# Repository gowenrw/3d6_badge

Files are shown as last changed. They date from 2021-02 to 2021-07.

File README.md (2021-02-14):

# 3d6 Badge

This is where all the files for the 3d6 Badge will be stored.  
This includes code and art and cad and fab files.  All the things.

## File Structure

This is the file structure of this repository

* [/](/README.md) - YOU ARE HERE
* [/art/](./art/) - Artwork and other graphics created by this project
  * /art/inspiration/ - Art and graphics pulled from other sources used as inspiration for this project
* [/code/](./code/) - All project related Code / Firmware
  * /code/altbier_pcb/ - Code folder for the production PCB(s)
  * /code/include/ - Common code includes (e.g. chipset drivers, etc.) used by the other code folders
* [/docs/](./docs/) - Documentation created by this project including web pages
* [/eda/](./eda/) - Electronic Design Automation files (i.e. KiCad)
  * /eda/altbier_pcb_3d6/ - KiCad project folder for the named project PCB(s)
* [/reference_parts/](./reference_parts/) - Documentation pulled from other sources related to components
* [./README.md](/README.md) - This File
* [./LICENSE](/LICENSE) - Currently set to MIT

Note: the reference_parts directory a link to a submodule repository.
To add it use the following cmd after downloading this template:
```
git submodule add https://github.com/gowenrw/reference_parts reference_parts
```
This will make a link to the current commit of that repo.
To update it to a newer commit after its been added use this cmd:
```
git submodule update --recursive
```

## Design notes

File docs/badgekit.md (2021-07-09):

---
layout: default
---

# 3d6 Badge Kit

The 3d6 badge kit that I am distributing contains the following items:

*  A fully assembled badge with attached battery holder
*  A Lanyard
*  3xAAA Batteries
*  A pencil with clip (for attaching to the lanyard)
*  Stickers

Badge_Kit

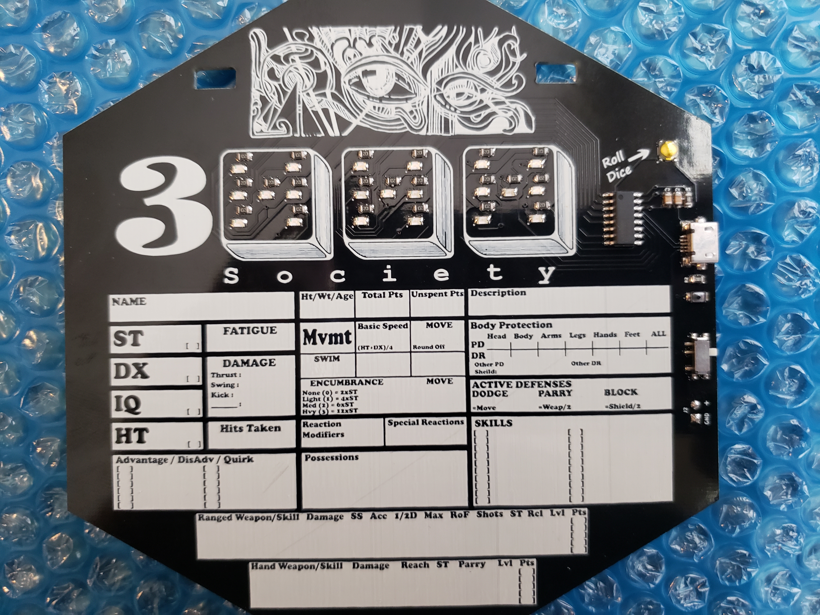
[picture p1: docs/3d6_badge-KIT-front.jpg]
Badge_Kit-Front


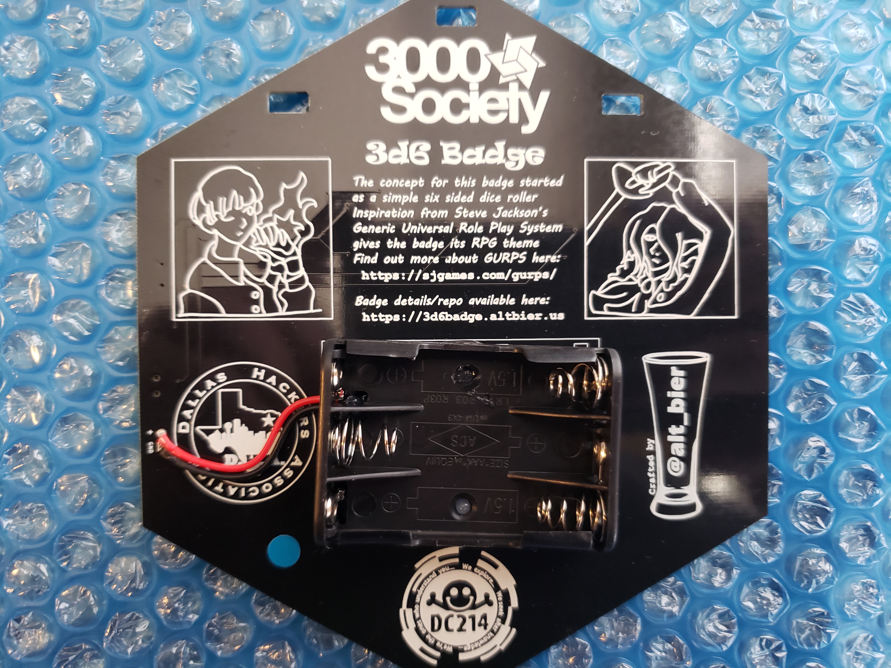
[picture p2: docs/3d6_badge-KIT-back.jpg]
Badge_Kit-Back


## Badge LED Colors

The majority of the badges I have created have Blue LEDs on them.

However, I have made limited numbers of badges with other LED colors including Red, and Pink as well as some multi-colored badges (one color per die) such as Red-White-Blue.

Badge_Colors

## Lanyard

There are several styles of lanyards since I did multiple lanyard runs.

These lanyards were randomly distributed in the kits.
So, you may get one with plastic clips or metal clips or large block lettering or small logo lettering.

They all function the same.

Badge_Kit-Lanyard

## Batteries

The batteries provided are a standard AAA non-rechargeable type.

Given the small power draw of the badge the provided batteries should last for the entire DEFCON conference (4+ days).

These can be replaced with any off the shelf AAA batteries.  

## Pencil with clip

The pencil provided is a small golf type pencil with an eraser.
It has had a clip added to it that allows for it to be attached to the lanyard.

Care should be taken to attach it securely or risk having it fall off into the void.
I would suggest attaching it into the small sewn gap holding a lanyard clip.

## Stickers

The kit contains two stickers.
The first is a new creation using the DEFCON 29 theme colors on a black background.
The second is from last years BSidesDFW Hardware Hacking Village

## Thanks

Thank You for your interest in my badge.

-- [@alt_bier](https://twitter.com/alt_bier)  - [My Contact Info](https://gowen.net/about)

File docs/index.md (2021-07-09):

---
layout: default
---

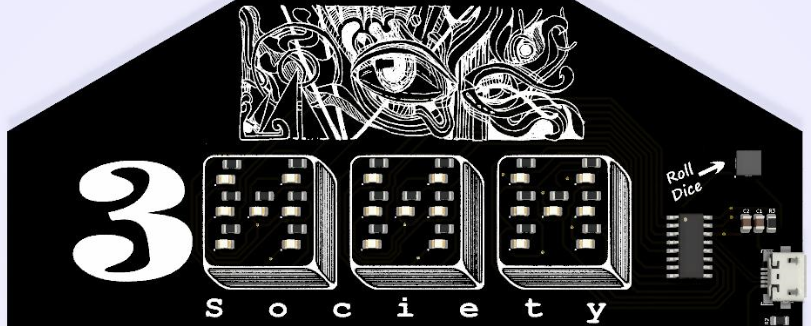
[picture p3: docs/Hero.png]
Hero Image


# 3d6 Badge

Welcome to the 3d6 Badge website.

This is where you will find information about the 3d6 badge and its repository.

-- [@alt_bier](https://twitter.com/alt_bier)  - [My Contact Info](https://gowen.net/about)

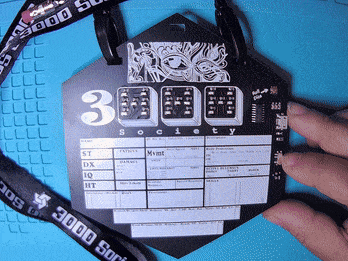
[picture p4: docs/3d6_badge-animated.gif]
Animated


---

# Concept

The concept for this badge started as a simple six sided dice roller.
It was originally just going to have two dice on it and be quite small.
But, then after discussions in the 3000 Society gaming group inspiration hit.
If we added a 3rd die the resulting 3d6 layout would be perfect for GURPS.
And thus the concept changed and the badge expanded into the GURPS player character sheet you see here.

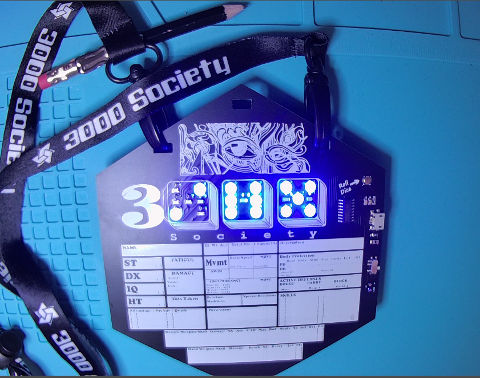
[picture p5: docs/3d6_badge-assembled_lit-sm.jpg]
Assembled-lit-small


For those not familiar with GURPS: it is the Generic Universal Role Play System developed by Steve Jackson.
You can get more information about it here: https://sjgames.com/gurps/

# Badge Kit

If you are looking for what comes in the badge kit, those details are here: [3d6 Badge Kit](badgekit.md)

# Badge Details

The details of the badge including the PCB design files and firmware and artwork are all included in this repository.

We will outline some of those details here.

## Silkscreen

The silkscreen on the front of the badge contains the GURPS player character sheet blocks (that can be written on with the included clip on pencil), the dice outlines which make up the 3000 Society logo, and a cool looking block of art at the top.

The top art block was created by my son.  I asked him to create something cool that was reminiscent of the small art blocks used as section headings in old school D&D adventure modules.
What he came up with was spectacular and captured that RPG module essence.

The silkscreen on the back of the badge contains several logos and links as well as two character portraits as one might find on an RPG character sheet.

The art for the character portraits were created by my daughter.  I asked her to create portraits of a generic magic user and melee class.  The limitations of the silkscreen media (e.g. no shading, line separation, etc.) meant she could not provide the usual detail she does with the portraits she creates for our family RPG characters.
Despite this challenge the end result is awesome and really brings the character sheet badge concept to life.

The art used for the silkscreen is available in the [art directory](https://github.com/gowenrw/3d6_badge/tree/main/art) of this repository.

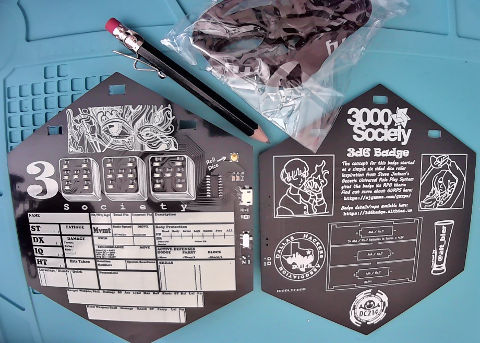
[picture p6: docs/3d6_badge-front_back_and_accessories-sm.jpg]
Front_and_Back-small


## Dice

The dice are each made up of seven LEDs arraigned to be able to lite up one through six with the look of a standard six sided die.
These LEDs are grouped into three pairs and a single so that each die requires only 4 microcontroller pins to control.

With the expansion from two to three dice the required pins went from eight to twelve, maxing out the microcontroller I chose for the badge.
With no remaining pins for a button to roll the dice I had to use the chip reset pin for this function.  So, hitting the 'Roll Dice' button is the same a powering it off and on again.

## Microcontroller

The microcontroller I chose for this badge is the CH552G IC that I have used on several other badges.  It is usually inexpensive and simple to use.

The chip shortage impacted price and availability of the CH552G.  
However, even with the higher price it was still a cheaper option than the other ICs out there.

If you want more detail about the CH552G chip I put together a video about it here:
[Intro to the CH552G Microcontroller](https://www.youtube.com/watch?v=EKhntUyfqhQ&lc=Ugyt9iKp8tLhYibYOgh4AaABAg)

The firmware for the badge and the header files for working with the CH552G are available in the [code directory](https://github.com/gowenrw/3d6_badge/tree/main/code) of this repository.

## EDA

The electronic design automation program used for this badge is KiCad.

I took great care to include and use local library files for all the schematic objects, footprints, and 3d models used in this badge.  
This way you don't have to worry about not having a file that KiCad depreciates at some point in the future.

All of the EDA files including the Gerber output files I used to have the badge manufactured are available in the [eda directory](https://github.com/gowenrw/3d6_badge/tree/main/eda) of this repository.

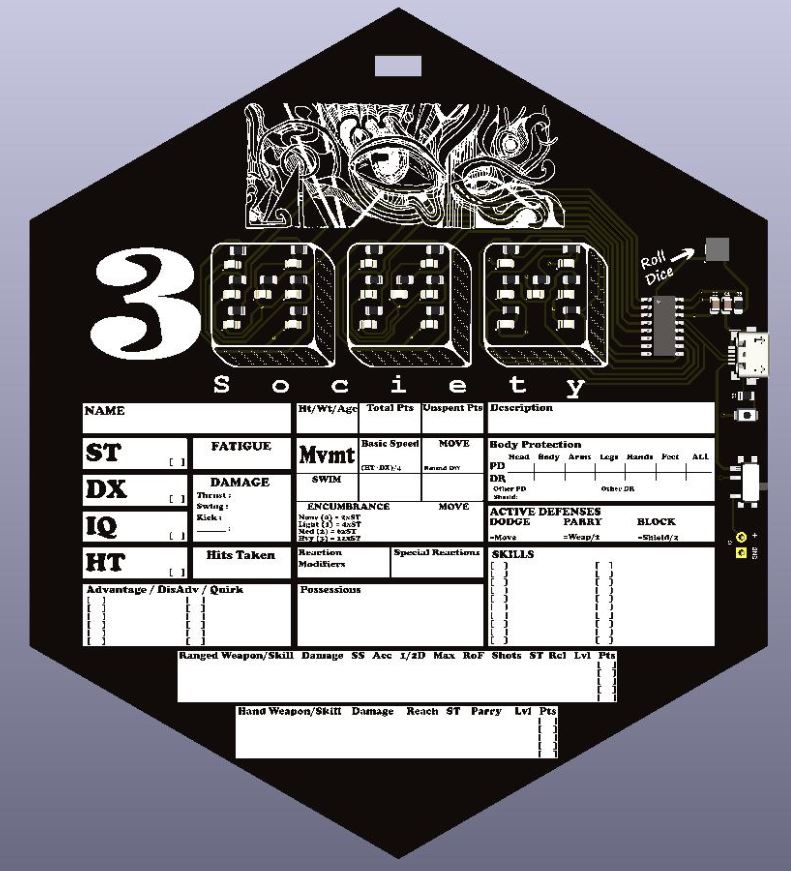
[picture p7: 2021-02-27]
eda/altbier_pcb_3d6/snapshots/altbier_pcb_3d6_3Dsnap2_crop.jpg

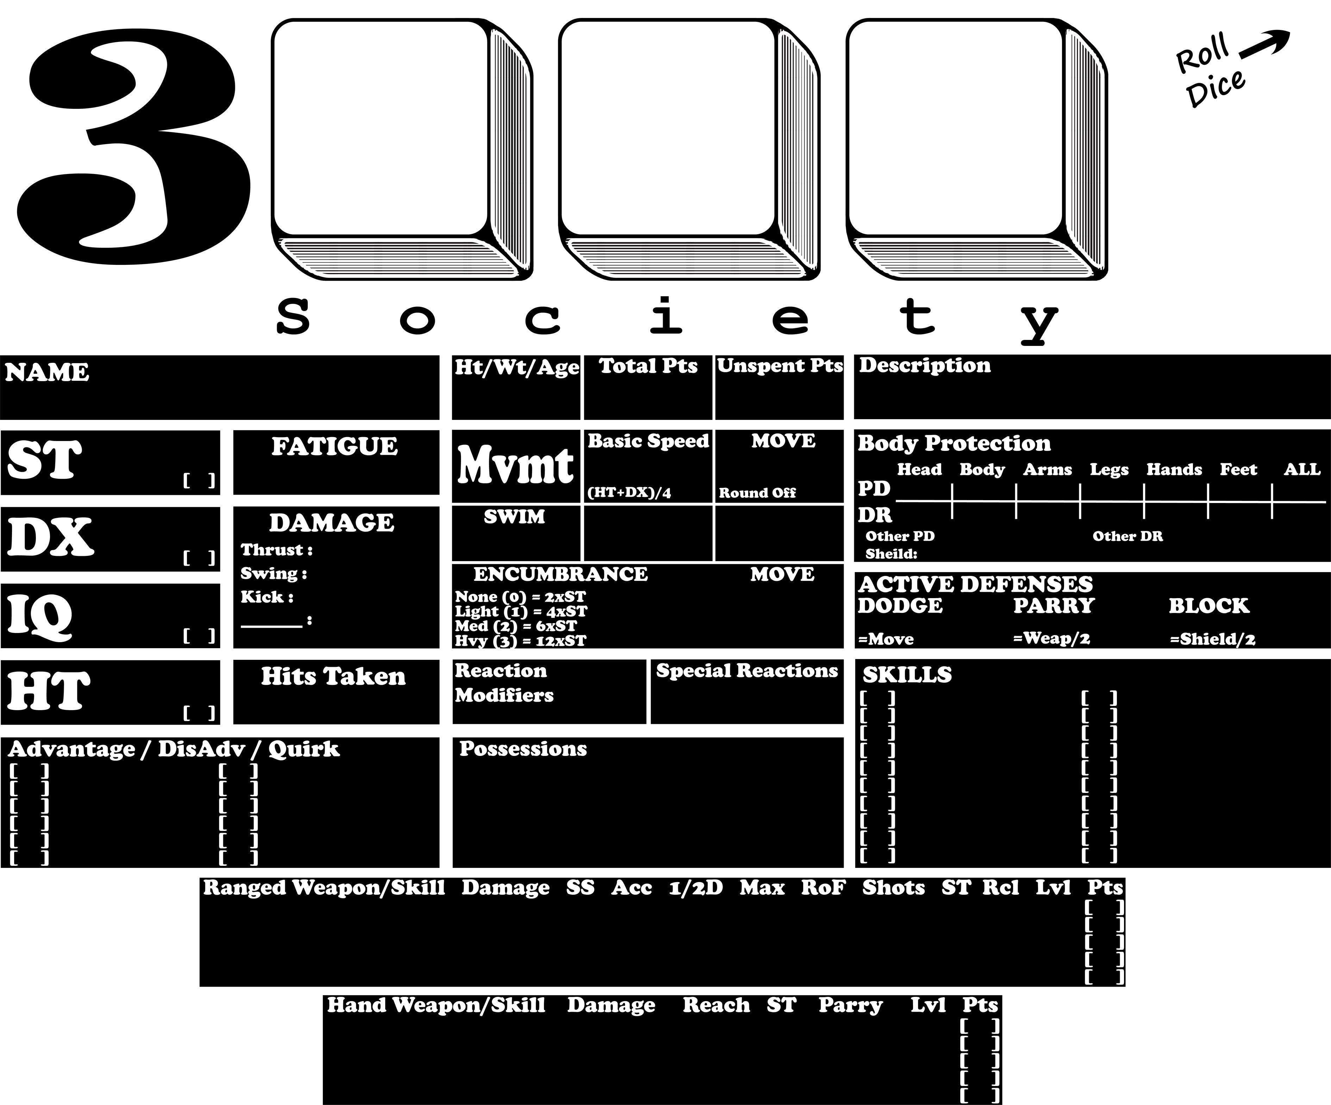
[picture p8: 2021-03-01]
art/3d6art2a.jpg

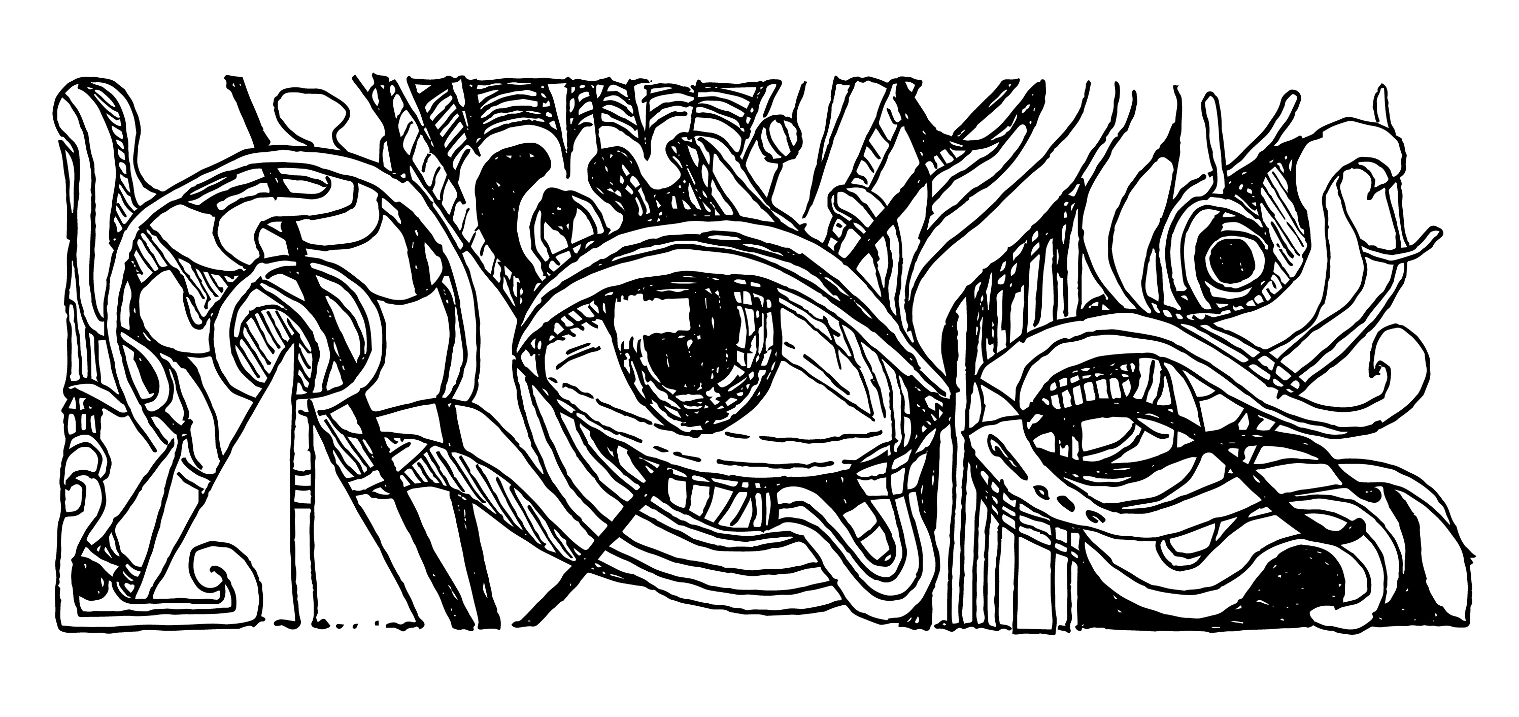
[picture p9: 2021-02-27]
art/Elliott-HandDrawn1.jpg

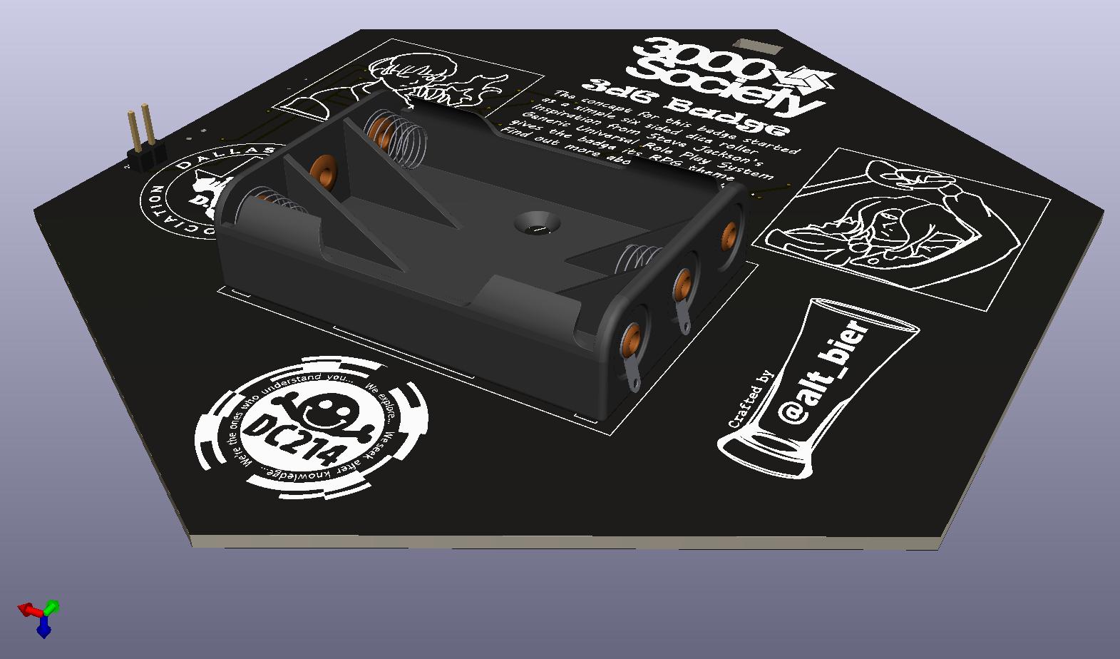
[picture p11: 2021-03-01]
eda/altbier_pcb_3d6/snapshots/altbier_pcb_3d6_3Dsnap4.jpg

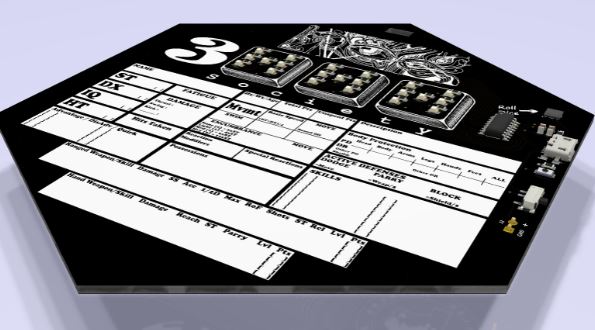
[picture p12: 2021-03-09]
eda/altbier_pcb_3d6/snapshots/altbier_pcb_3d6_3Dsnap3_small.jpg

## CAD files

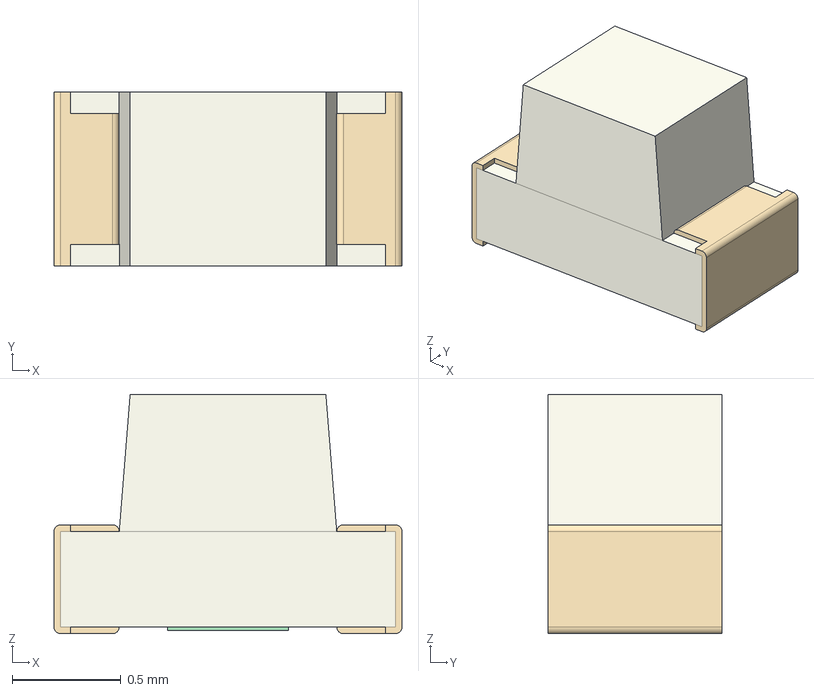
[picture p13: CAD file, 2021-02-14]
eda/altbier_pcb_3d6/3d_models/LED_0603_1608Metric.step
1.60 x 0.8 x 1.10 mm

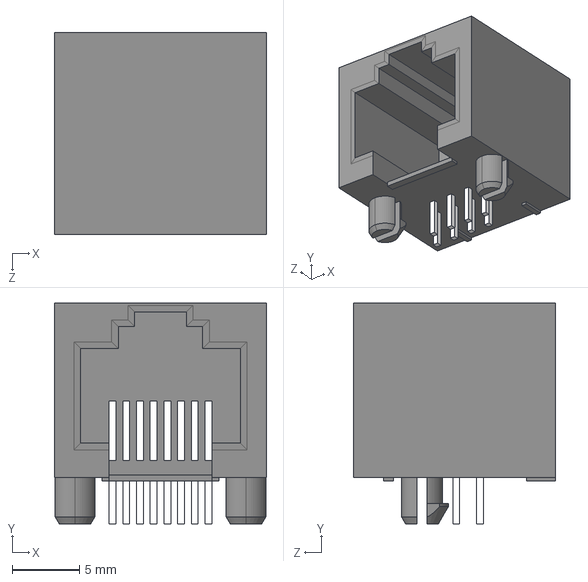
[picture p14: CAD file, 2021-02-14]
eda/altbier_pcb_3d6/3d_models/RJ45_Amphenol_RJHSE-5080-56544.STEP
15.7 x 16.4 x 15.0 mm

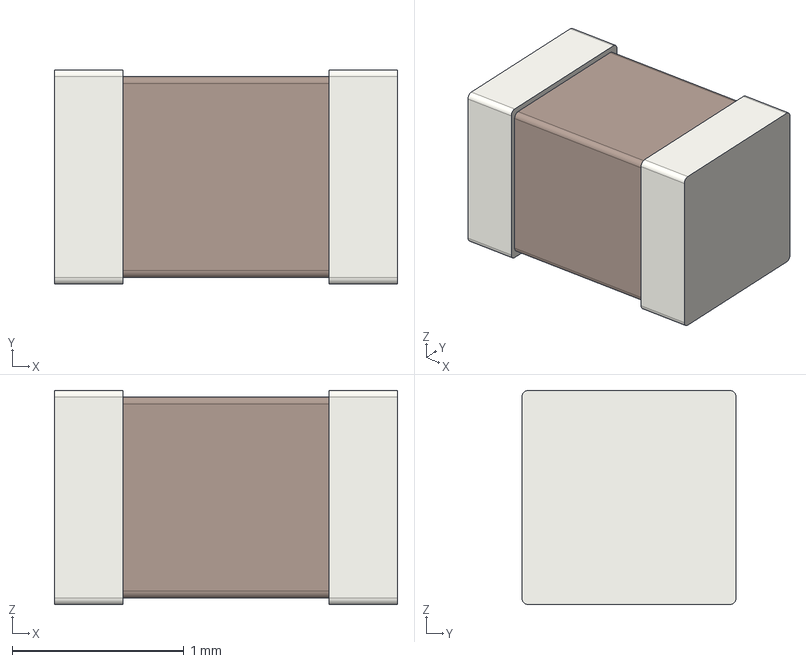
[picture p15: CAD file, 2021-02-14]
eda/altbier_pcb_3d6/3d_models/C_0805_2012Metric.step
2.00 x 1.25 x 1.25 mm

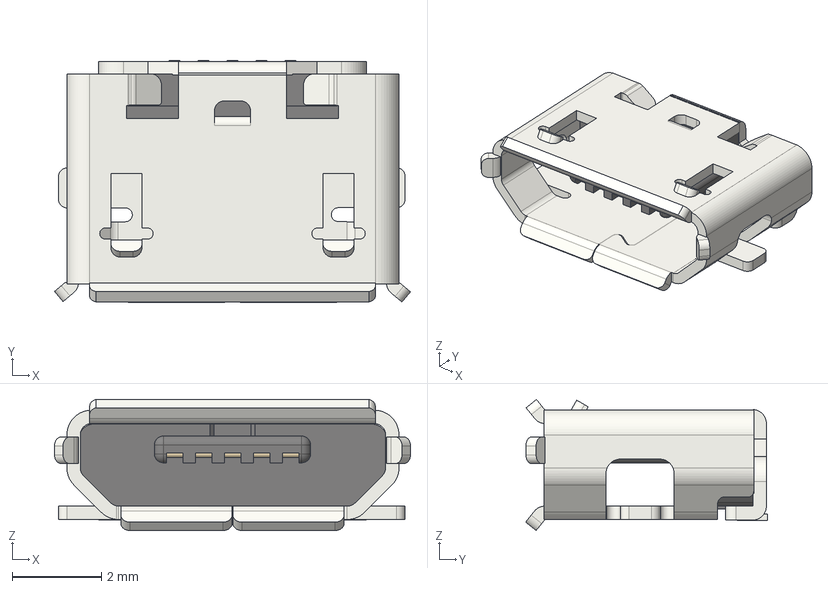
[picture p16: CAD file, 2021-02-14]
eda/altbier_pcb_3d6/3d_models/USB_Micro-B_Molex_47346-0001.step
7.98 x 5.42 x 2.94 mm

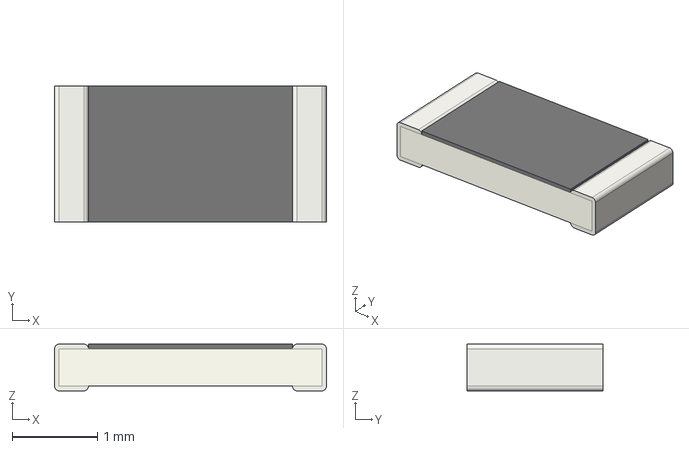
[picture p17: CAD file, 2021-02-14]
eda/altbier_pcb_3d6/3d_models/R_1206_3216Metric.step
3.20 x 1.60 x 0.55 mm

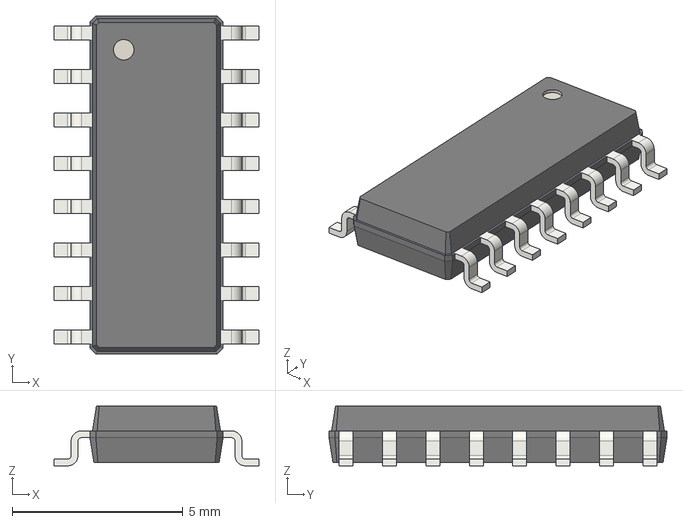
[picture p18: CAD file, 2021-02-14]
eda/altbier_pcb_3d6/3d_models/SOIC-16_3.9x9.9mm_P1.27mm.step
6.00 x 9.90 x 1.75 mm

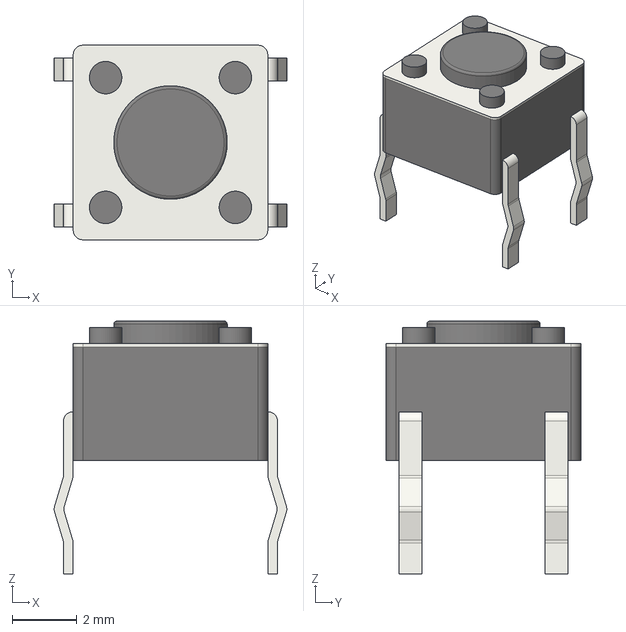
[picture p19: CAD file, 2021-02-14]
eda/altbier_pcb_3d6/3d_models/SW_PUSH_6mm.step
7.17 x 6.00 x 7.80 mm

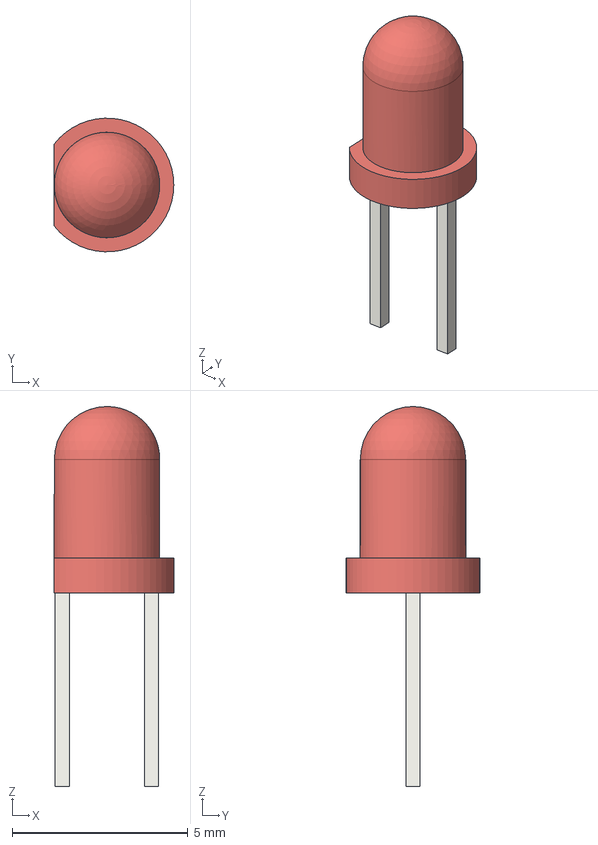
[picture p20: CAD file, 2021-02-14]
eda/altbier_pcb_3d6/3d_models/LED_D3.0mm.step
3.40 x 3.80 x 10.8 mm

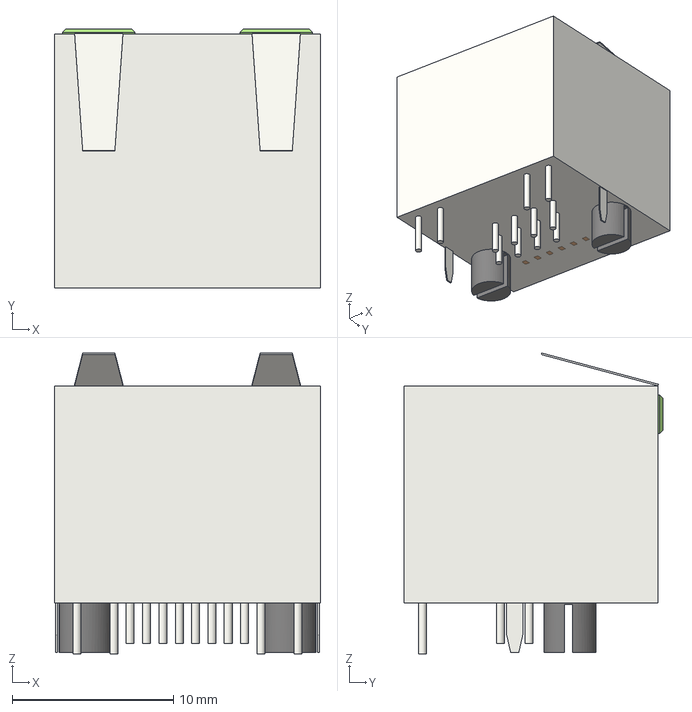
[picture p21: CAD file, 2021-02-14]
eda/altbier_pcb_3d6/3d_models/RJ45_Amphenol_RJHSE538X.step
16.5 x 16.1 x 18.7 mm

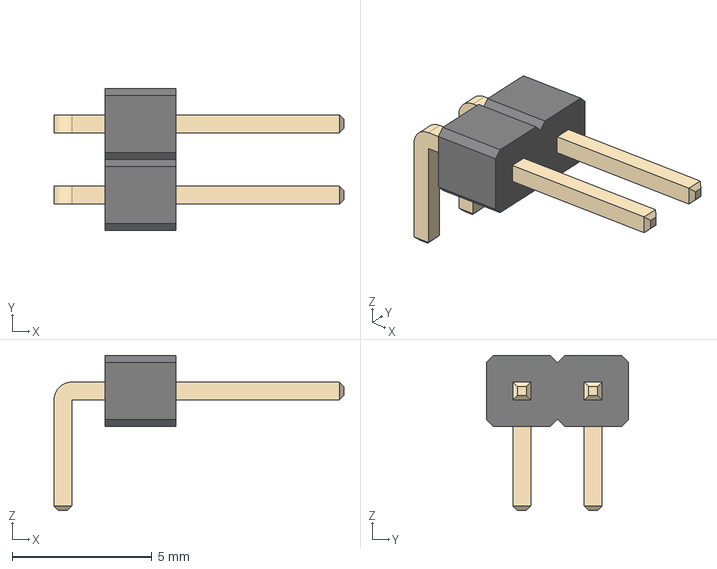
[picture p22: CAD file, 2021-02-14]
eda/altbier_pcb_3d6/3d_models/PinHeader_1x02_P2.54mm_Horizontal.step
10.4 x 5.08 x 5.54 mm

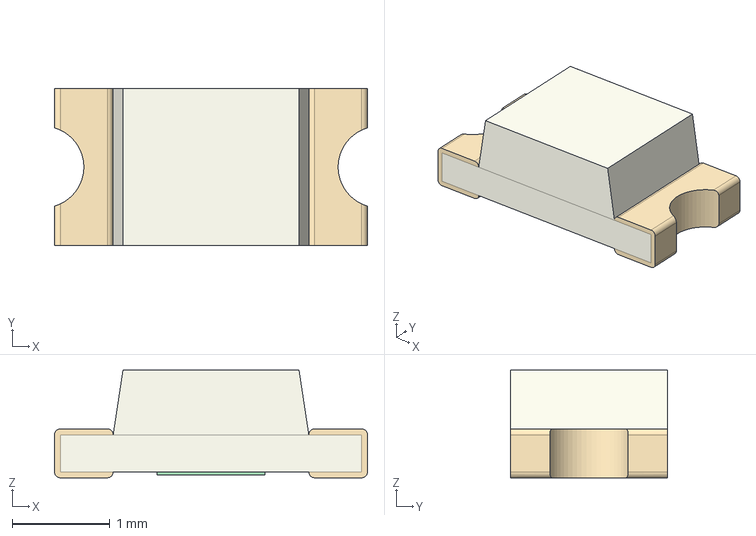
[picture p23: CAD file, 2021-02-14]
eda/altbier_pcb_3d6/3d_models/LED_1206_3216Metric_Castellated.step
3.20 x 1.60 x 1.10 mm

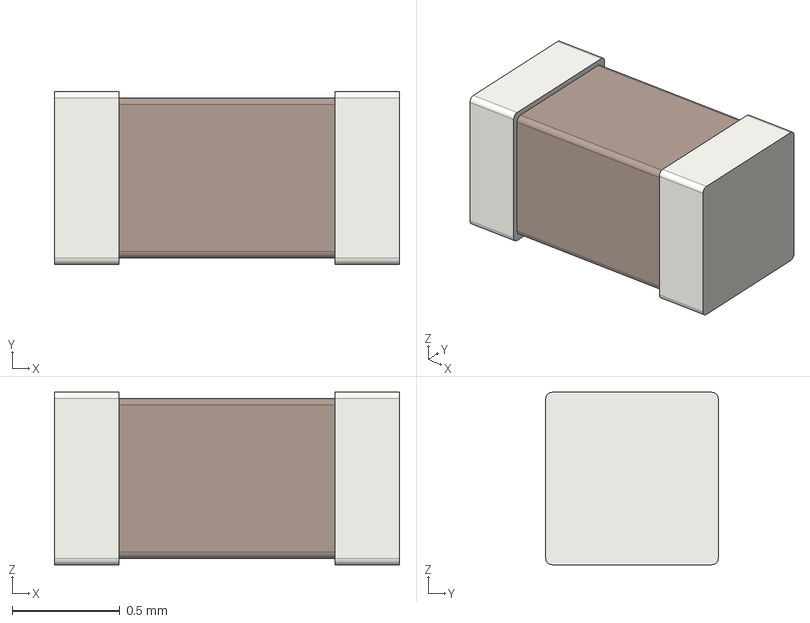
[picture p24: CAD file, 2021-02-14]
eda/altbier_pcb_3d6/3d_models/C_0603_1608Metric.step
1.60 x 0.8 x 0.8 mm

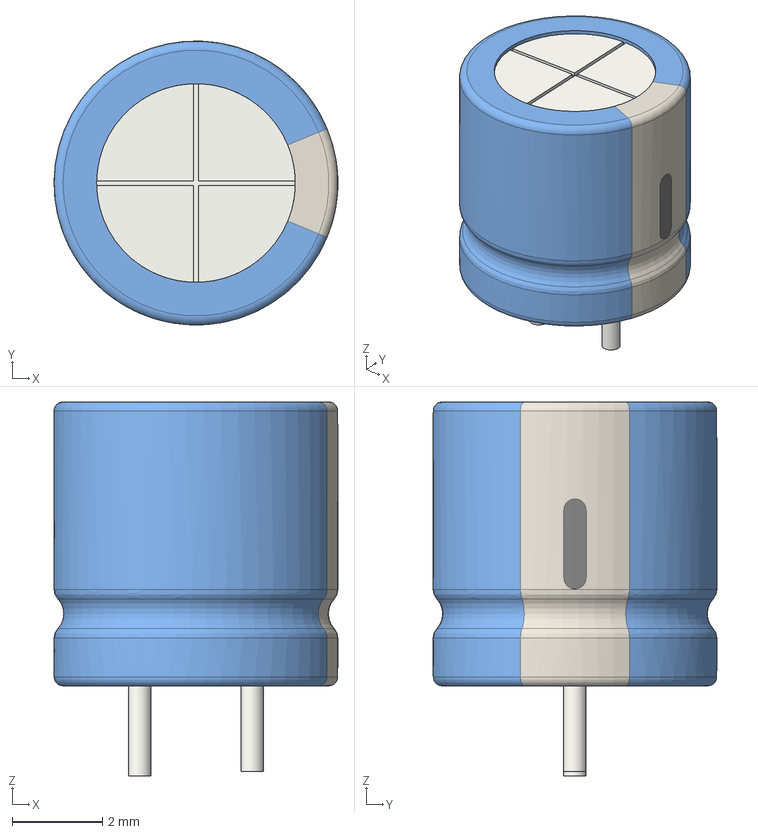
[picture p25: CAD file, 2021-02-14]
eda/altbier_pcb_3d6/3d_models/CP_Radial_D6.3mm_P2.50mm.step
6.30 x 6.30 x 8.30 mm

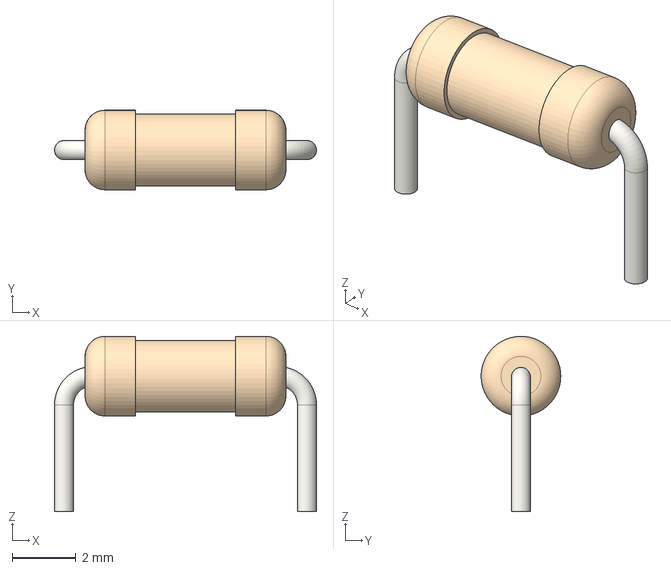
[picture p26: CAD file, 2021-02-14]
eda/altbier_pcb_3d6/3d_models/R_Axial_DIN0207_L6.3mm_D2.5mm_P7.62mm_Horizontal.step
8.22 x 2.50 x 5.50 mm

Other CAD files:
eda/altbier_pcb_3d6/3d_models/LED_0603_1608Metric_Castellated.step
eda/altbier_pcb_3d6/3d_models/LED_D5.0mm-4_RGB.step
eda/altbier_pcb_3d6/3d_models/R_0805_2012Metric.step
eda/altbier_pcb_3d6/3d_models/Battery_Holder_3xAAA_Simple.step
eda/altbier_pcb_3d6/3d_models/C_1206_3216Metric.step
eda/altbier_pcb_3d6/3d_models/C_Disc_D3.0mm_W2.0mm_P2.50mm.step
eda/altbier_pcb_3d6/3d_models/C_Rect_L4.6mm_W2.0mm_P2.50mm_MKS02_FKP02.step
eda/altbier_pcb_3d6/3d_models/LED_0805_2012Metric.step
eda/altbier_pcb_3d6/3d_models/LED_0805_2012Metric_Castellated.step
eda/altbier_pcb_3d6/3d_models/LED_1206_3216Metric.step
eda/altbier_pcb_3d6/3d_models/LED_D5.0mm-4_RGB_Neo.step
eda/altbier_pcb_3d6/3d_models/LED_D5.0mm.step
eda/altbier_pcb_3d6/3d_models/LED_D8.0mm.step
eda/altbier_pcb_3d6/3d_models/PinHeader_1x02_P2.54mm_Vertical.step
eda/altbier_pcb_3d6/3d_models/PinHeader_1x08_P2.54mm_Horizontal.step
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

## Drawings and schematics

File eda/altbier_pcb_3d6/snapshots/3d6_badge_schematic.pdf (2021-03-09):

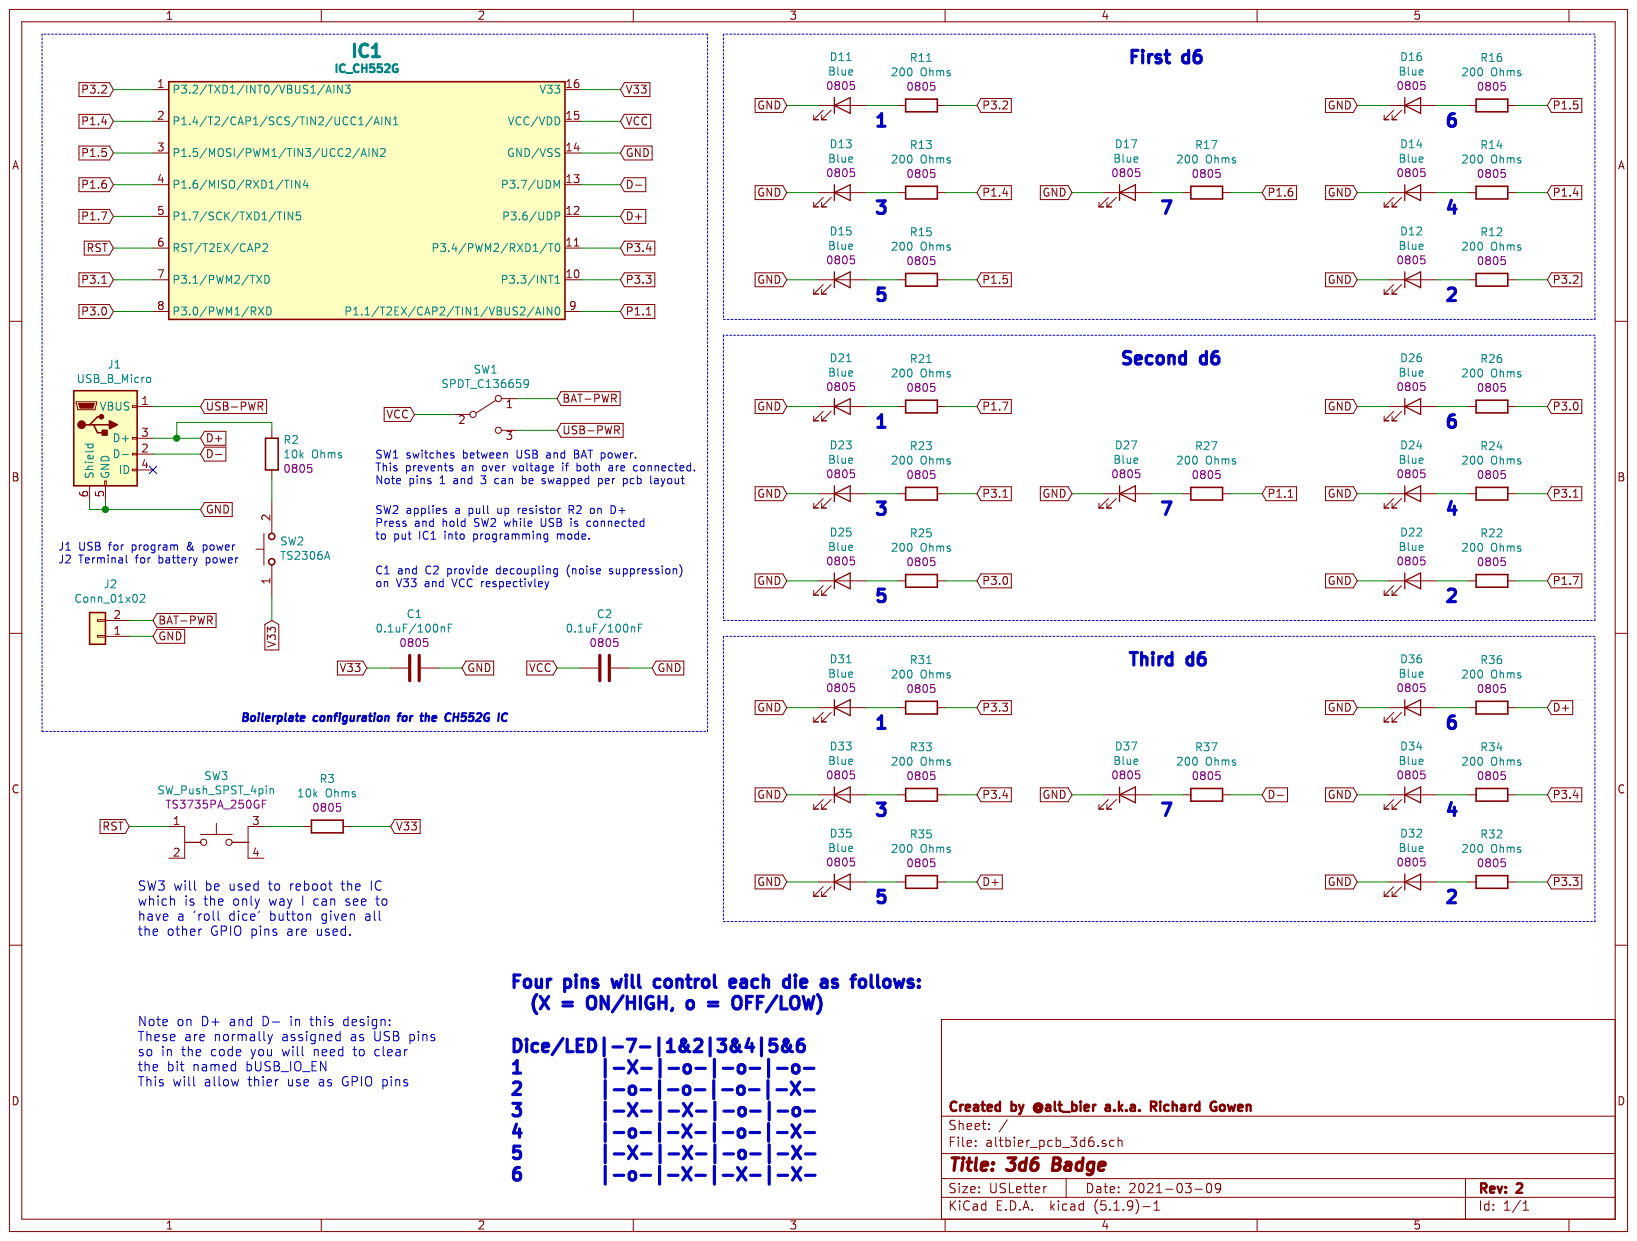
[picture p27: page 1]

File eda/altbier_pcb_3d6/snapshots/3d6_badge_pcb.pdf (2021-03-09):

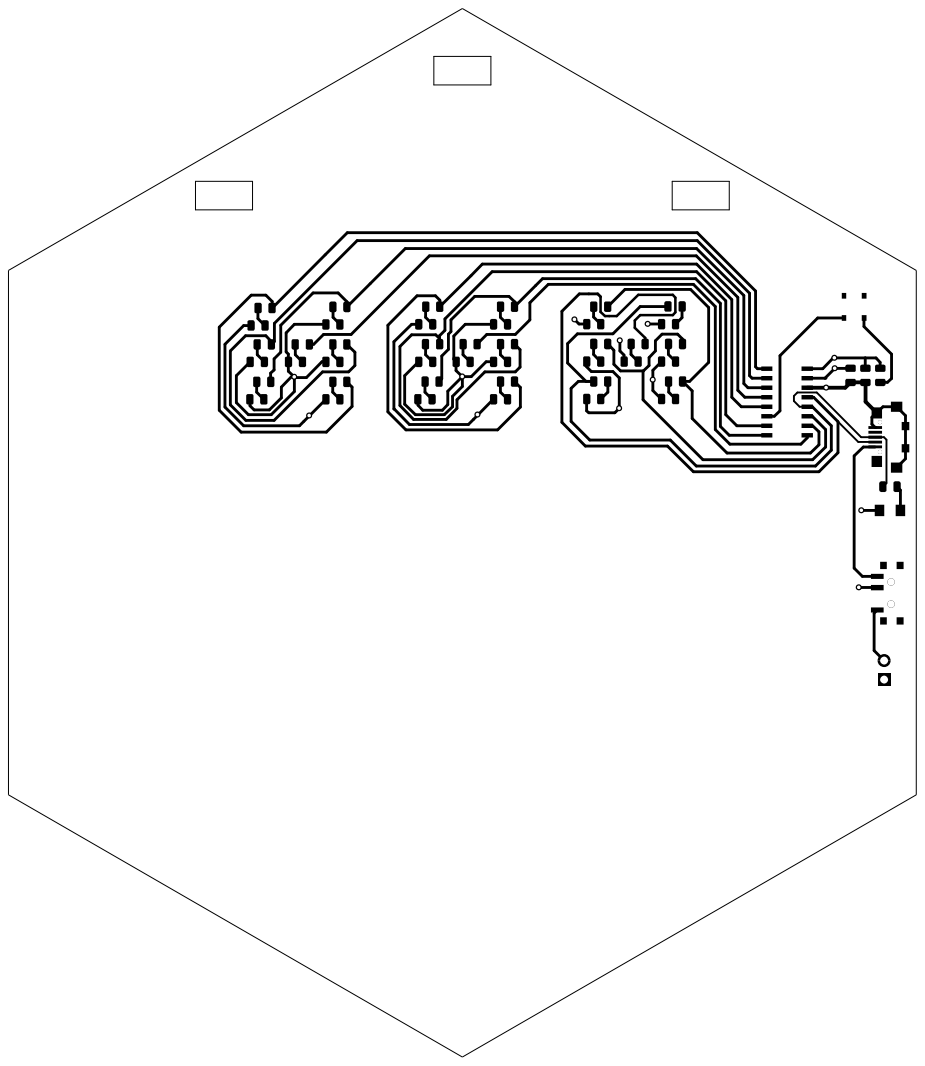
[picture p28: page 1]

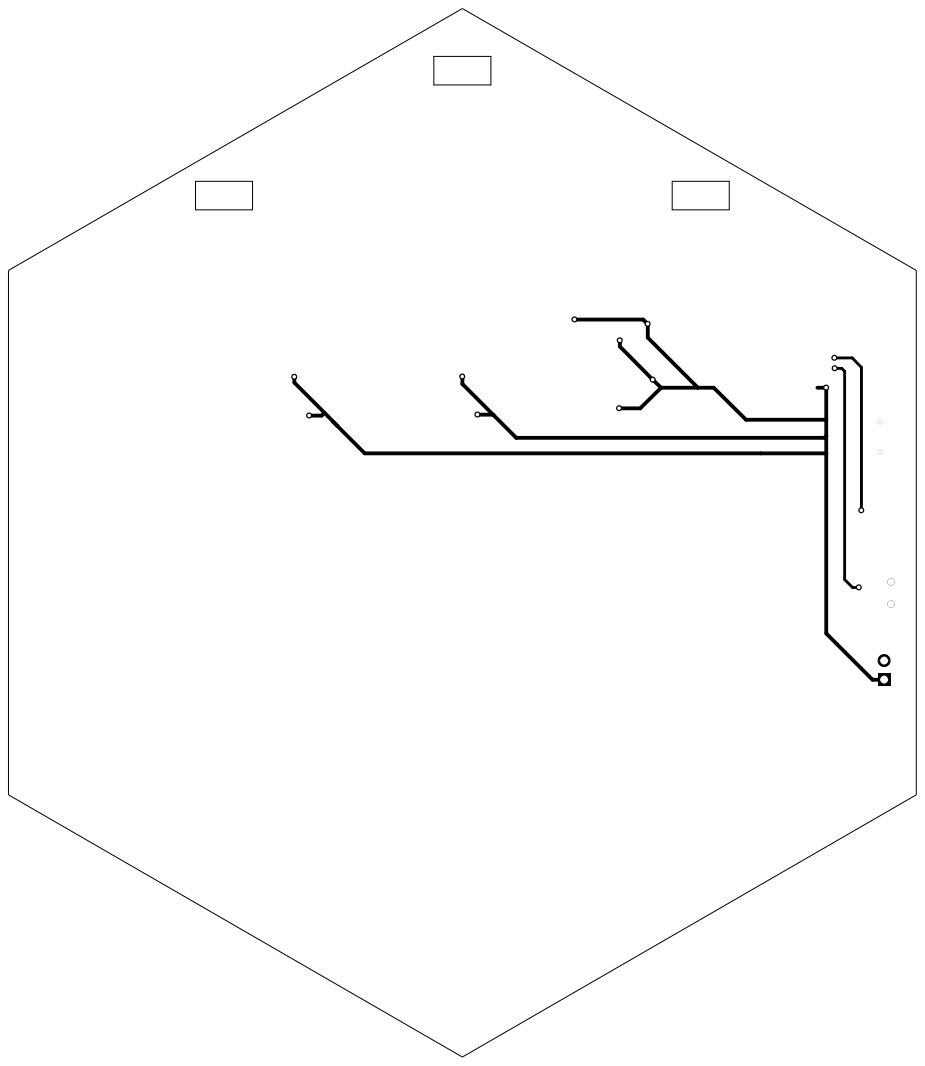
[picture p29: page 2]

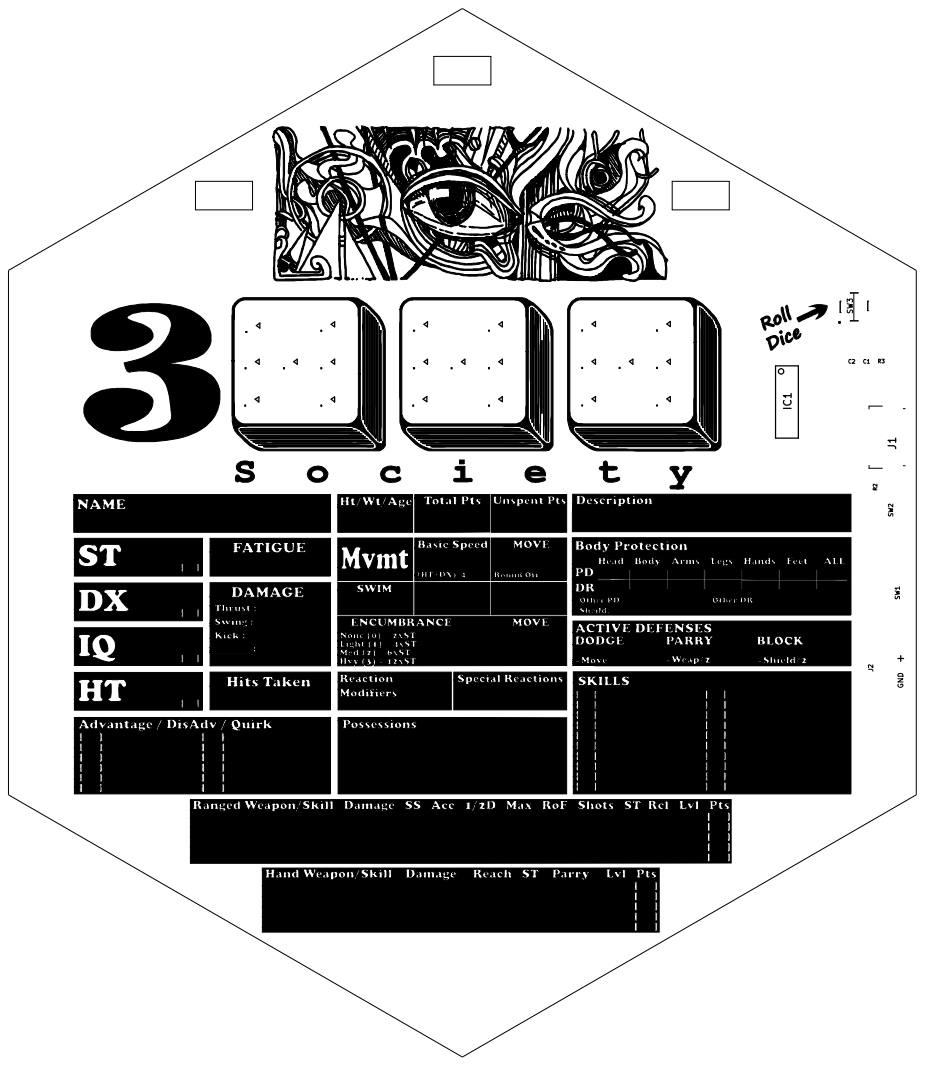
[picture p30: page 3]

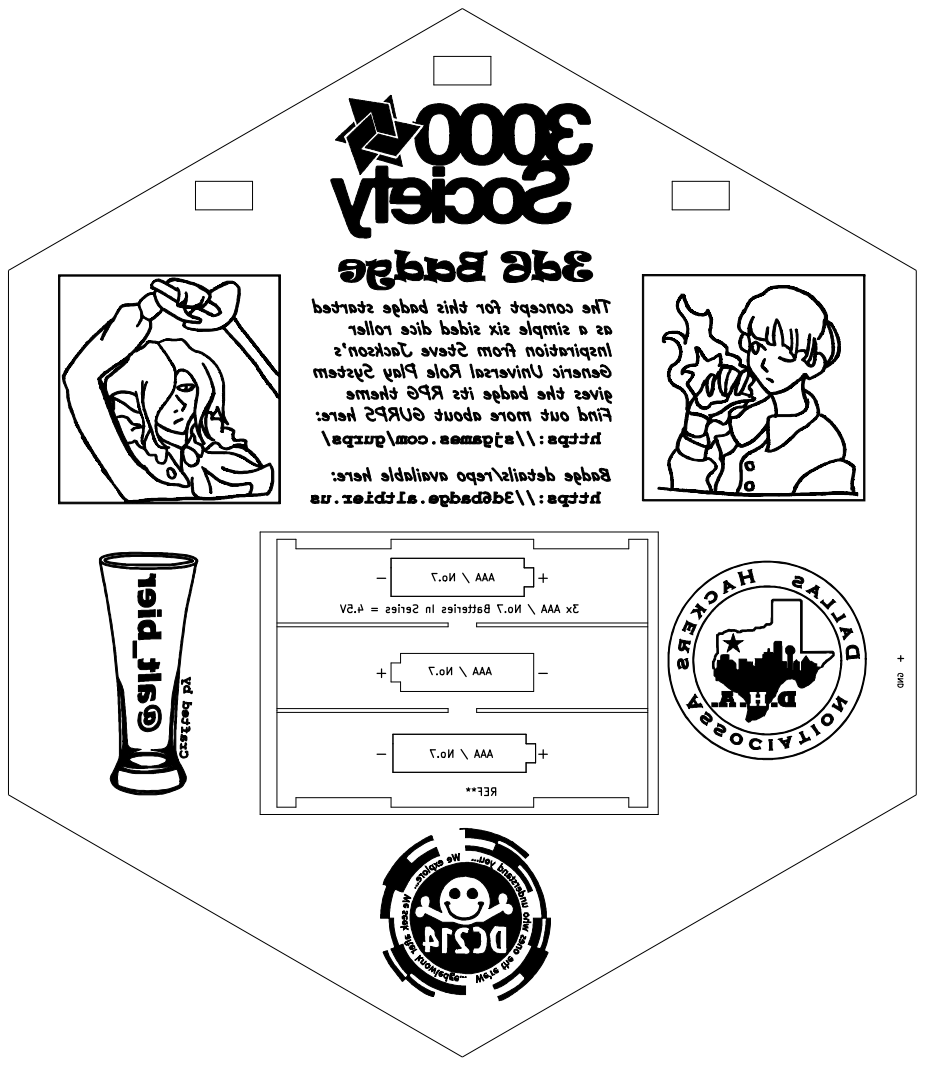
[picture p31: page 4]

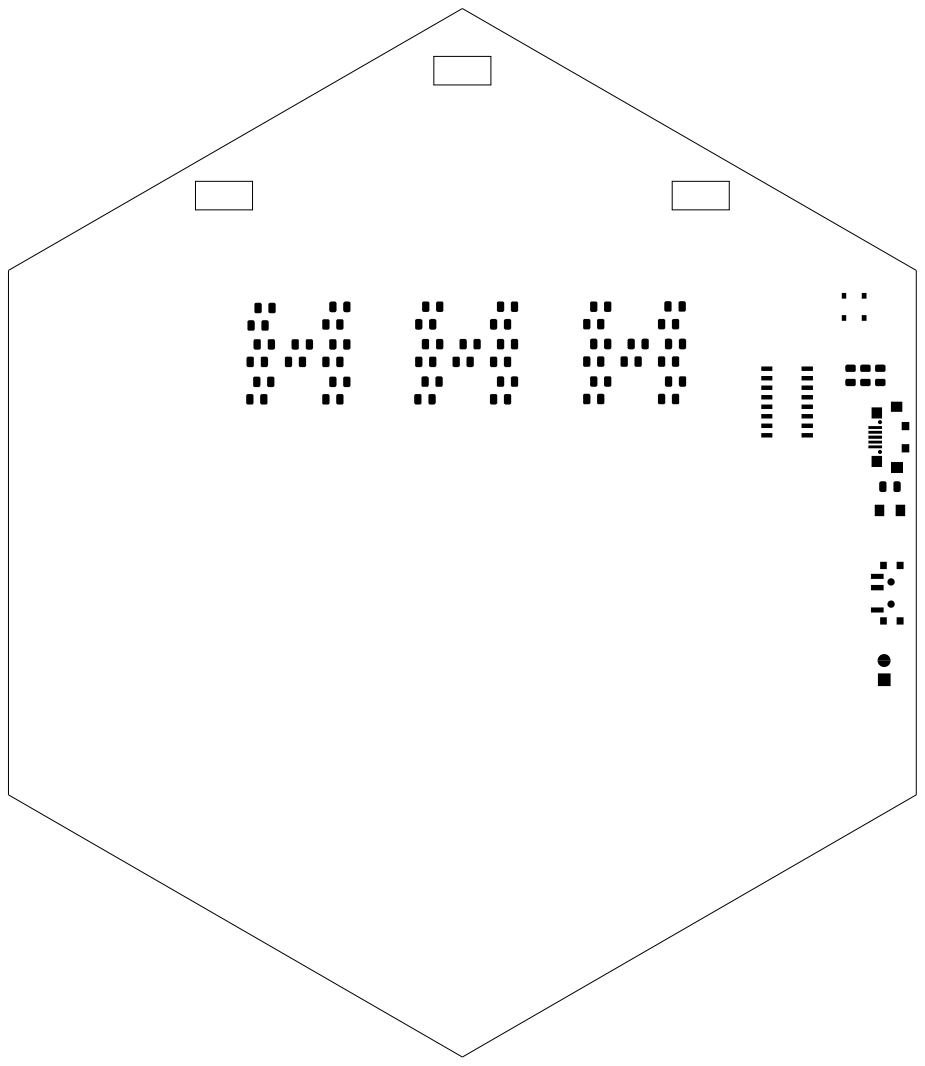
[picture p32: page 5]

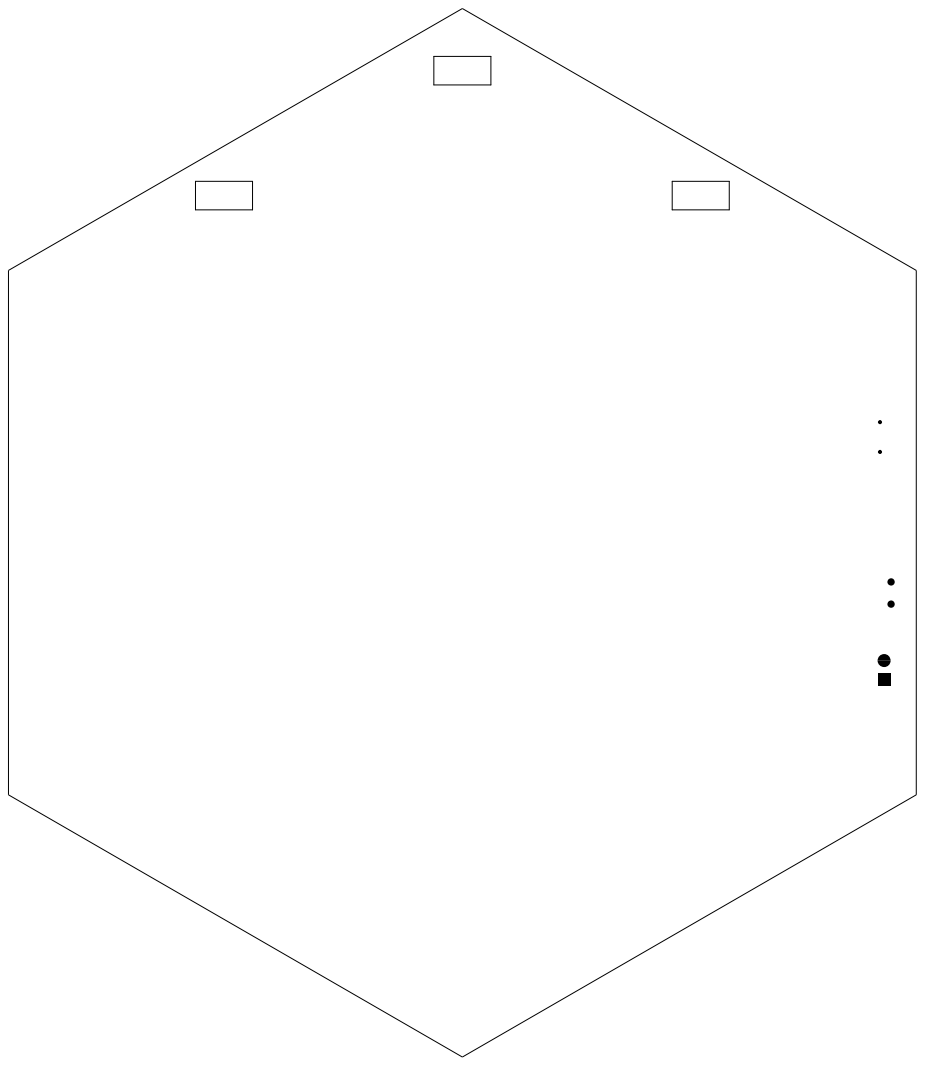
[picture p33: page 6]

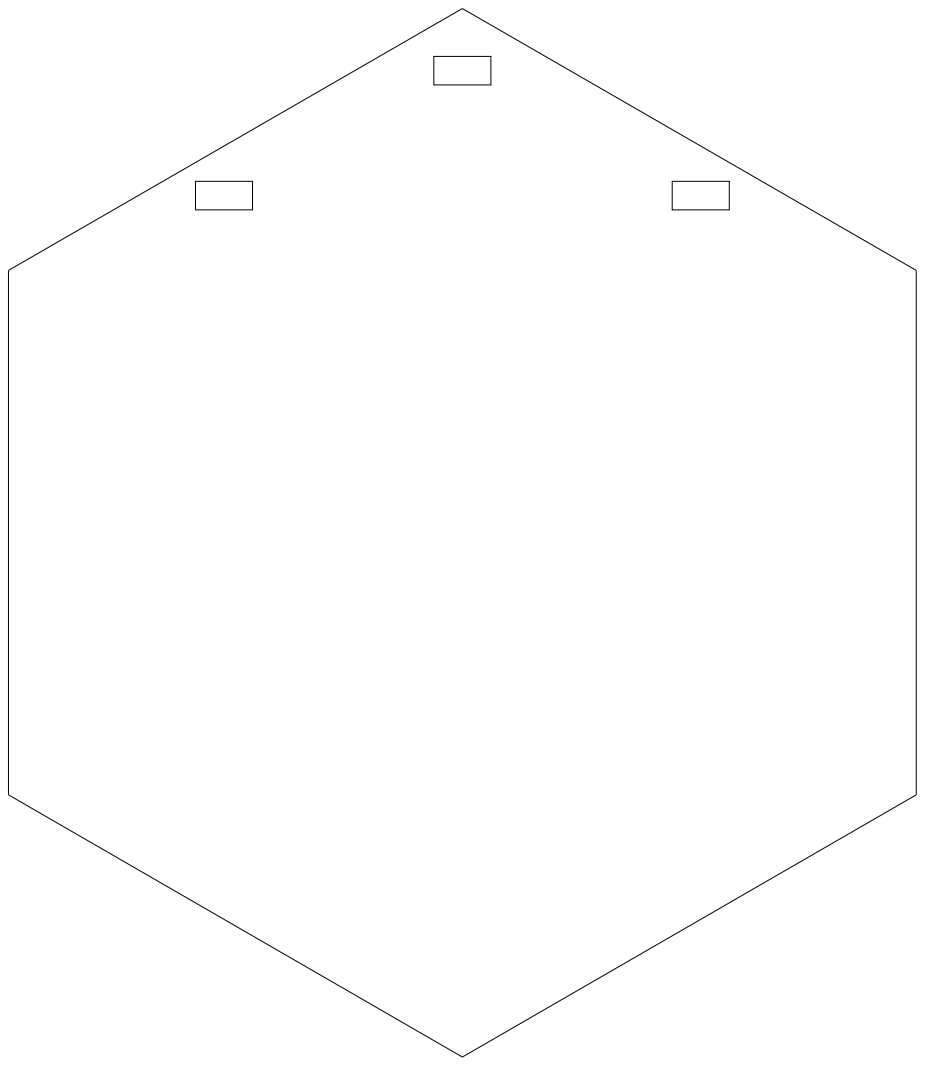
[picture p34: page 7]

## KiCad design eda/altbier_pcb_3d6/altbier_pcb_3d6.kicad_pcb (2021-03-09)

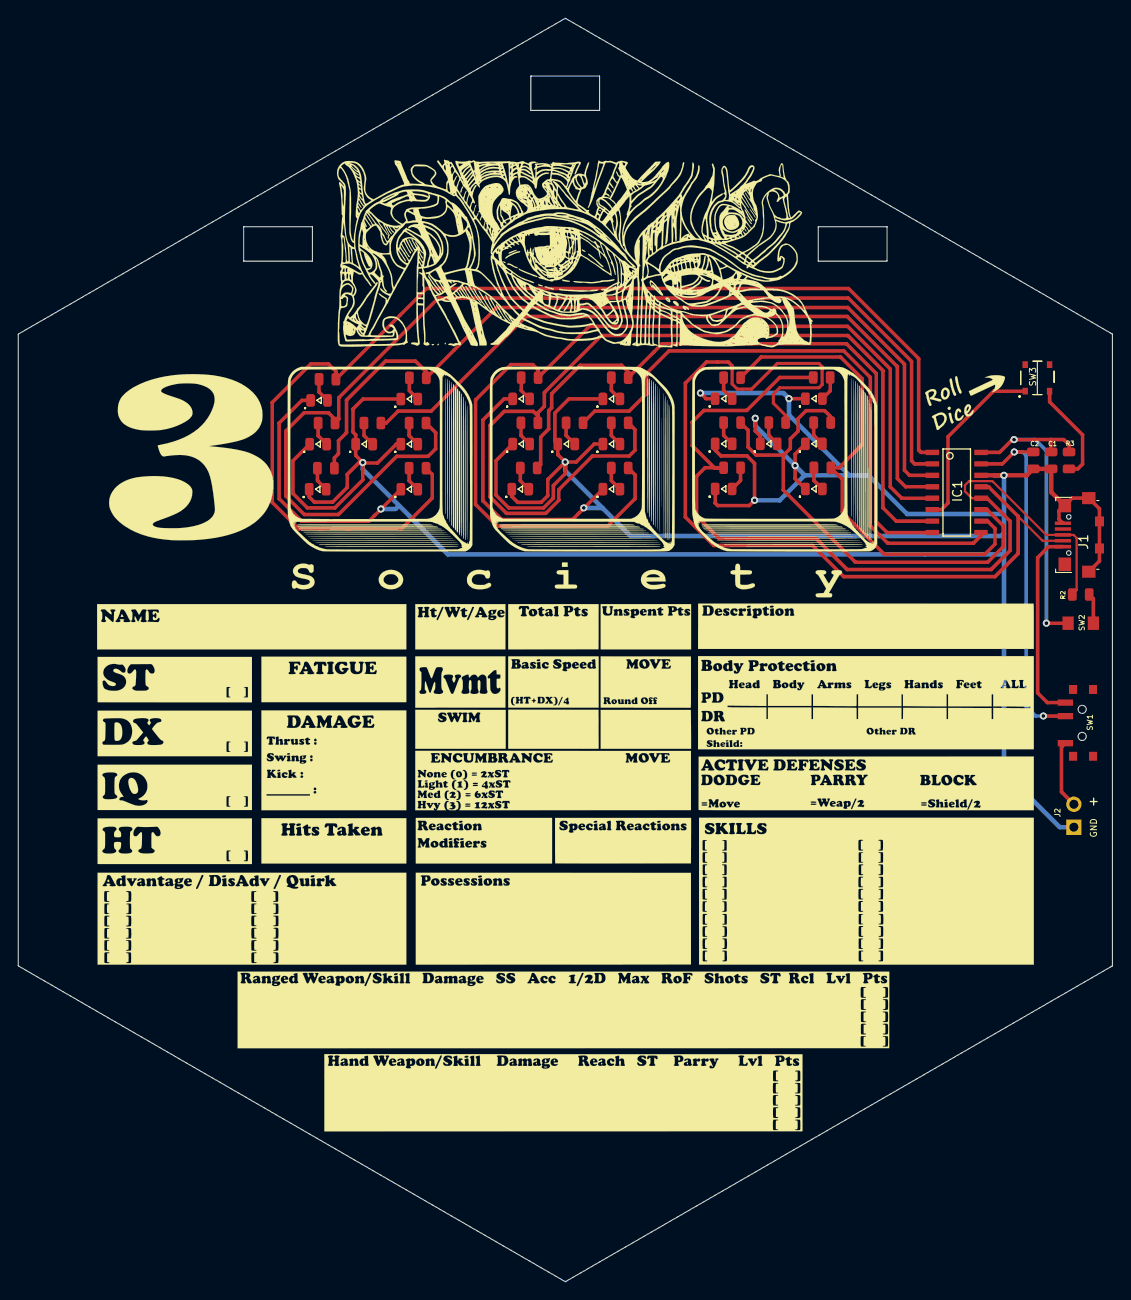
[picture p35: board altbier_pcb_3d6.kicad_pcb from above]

Board: 2 copper layers, 121.2 x 140.0 mm, 54 parts (0 on the bottom side), 41 nets.

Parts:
3d6: LOGO; 3d6_front_silk_925
C1, C2: 0.1uF/100nF; C_0805_2012Metric_low-silk
D11, D12, D13, D14, D15, D16, D17, D21, D22, D23, D24, D25, D26, D27, D31, D32, D33, D34, D35, D36, D37: Blue; LED_0805_2012Metric_low-silk
Elliott1: LOGO; Elliott_front_silk_675
IC1: IC_CH552G; IC_SOIC-16_3.9x9.9mm_Pitch1.27mm
J1: USB_B_Micro; USB_Micro-B_Jing
J2: Conn_01x02; Conn_Pin_Header_Straight_1x02_Pitch2.54mm_low-silk
R2, R3: 10k Ohms; R_0805_2012Metric_low-silk
R11, R12, R13, R14, R15, R16, R17, R21, R22, R23, R24, R25, R26, R27, R31, R32, R33, R34, R35, R36, R37: 200 Ohms; R_0805_2012Metric_low-silk
SW1: SPDT_C136659; SW_SPDT_PCM12_C136659_low-silk
SW2: TS2306A; SW_TS2306A240GFMSM9_C388290_low-silk
SW3: SW_Push_SPST_4pin; SW_TS3735PA250GF

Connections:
BAT-PWR: J2.2, SW1.1
D+: IC1.12, J1.3, R2.1, R35.2, R36.2
D-: IC1.13, J1.2, R37.2
GND: C1.1, C2.1, D11.1, D12.1, D13.1, D14.1, D15.1, D16.1, D17.1, D21.1, D22.1, D23.1, D24.1, D25.1, D26.1, D27.1, D31.1, D32.1, D33.1, D34.1, D35.1, D36.1, D37.1, IC1.14, J1.5, J1.6, J2.1
unnamed: D11.2, R11.1
unnamed: D12.2, R12.1
unnamed: D13.2, R13.1
unnamed: D14.2, R14.1
unnamed: D15.2, R15.1
unnamed: D16.2, R16.1
unnamed: D17.2, R17.1
unnamed: D21.2, R21.1
unnamed: D22.2, R22.1
unnamed: D23.2, R23.1
unnamed: D24.2, R24.1
unnamed: D25.2, R25.1
unnamed: D26.2, R26.1
unnamed: D27.2, R27.1
unnamed: D31.2, R31.1
unnamed: D32.2, R32.1
unnamed: D33.2, R33.1
unnamed: D34.2, R34.1
unnamed: D35.2, R35.1
unnamed: D36.2, R36.1
unnamed: D37.2, R37.1
unnamed: R2.2, SW2.2
unnamed: R3.1, SW3.3
P1.1: IC1.9, R27.2
P1.4: IC1.2, R13.2, R14.2
P1.5: IC1.3, R15.2, R16.2
P1.6: IC1.4, R17.2
P1.7: IC1.5, R21.2, R22.2
P3.0: IC1.8, R25.2, R26.2
P3.1: IC1.7, R23.2, R24.2
P3.2: IC1.1, R11.2, R12.2
P3.3: IC1.10, R31.2, R32.2
P3.4: IC1.11, R33.2, R34.2
RST: IC1.6, SW3.1
USB-PWR: J1.1, SW1.3
V33: C1.2, IC1.16, R3.2, SW2.1
VCC: C2.2, IC1.15, SW1.2

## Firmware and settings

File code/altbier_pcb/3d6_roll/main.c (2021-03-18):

/* *************************************************************************
* File Name          : 3d6_roll/main.c
* Author             : @alt_bier
* Date               : 2021/03/15
* Description        : Roll 3 six sided dice using pseudo random numbers
* Note on Random Seed: Without a real clock source or available analog pin
*                      we just read/write seed from flash.  So to prevent
*                      all devices having the same roll pattern you will
*                      need to manually set the initial seed random value
*                      in flash (bytes 0x001 and 0x002) on each firmware
*                      load since firmware load erases flash
*                      This could lead to some fun cheating recording the
*                      roll patterns of seeds to reset to before playing
************************************************************************* */
#include <ch552.h>
#include <debug.h>
#include <gpio.c>
#include <rand.c>
#include <DataFlash.c>

// Set Reference Bits - P1 = 0x90 P3 = 0xB0
// Left Side Pins (as seen top down)
SBIT(LED32, 0xB0, 2);  // Physical Pin 1
SBIT(LED14, 0x90, 4);  // Physical Pin 2
SBIT(LED15, 0x90, 5);  // Physical Pin 3
SBIT(LED16, 0x90, 6);  // Physical Pin 4
SBIT(LED17, 0x90, 7);  // Physical Pin 5
// RST                 // Physical Pin 6
SBIT(LED31, 0xB0, 1);  // Physical Pin 7
SBIT(LED30, 0xB0, 0);  // Physical Pin 8
// Right Side Pins (as seen top down)
// 3v3                 // Physical Pin 16
// vcc                 // Physical Pin 15
// gnd                 // Physical Pin 14
SBIT(LED37, 0xB0, 7);  // Physical Pin 13
SBIT(LED36, 0xB0, 6);  // Physical Pin 12
SBIT(LED34, 0xB0, 4);  // Physical Pin 11
SBIT(LED33, 0xB0, 3);  // Physical Pin 10
SBIT(LED11, 0x90, 1);  // Physical Pin 9

// define array for die values
UINT8 d6value[3];

// define vars for data flash
UINT8 addrn, lenn, buffn[2];

// define other main loop vars
UINT8 i, randomdie;
UINT16 seed;

void alloff() {
  // TURN ALL LEDS OFF
  LED11 = 0, LED14 = 0, LED15 = 0, LED16 = 0, LED17 = 0;
  LED30 = 0, LED31 = 0, LED32 = 0, LED33 = 0, LED34 = 0, LED36 = 0, LED37 = 0;
}

void dieoff(UINT8 die) {
  // Turn OFF one die
  if (die == 1) {
    // Die 1 LEDs
    // LED14, LED15, LED16, LED32
    LED14 = 0, LED15 = 0, LED16 = 0, LED32 = 0;
  }
  if (die == 2) {
    // Die 2 LEDs
    // LED11, LED17, LED30, LED31
    LED11 = 0, LED17 = 0, LED30 = 0, LED31 = 0;
  }
  if (die == 3) {
    // Die 3 LEDs
    // LED33, LED34, LED36, LED37
    LED33 = 0, LED34 = 0, LED36 = 0, LED37 = 0;
  }
}

void rollani(UINT8 die, UINT8 seq) {
  // Set LEDs ON for roll animation using sequence per die
  // The LED OFF state is set by the dieoff or alloff functions
  if (die == 1) {
    if (seq == 1) { LED32 = 1; }
    if (seq == 2) { LED14 = 1; }
    if (seq == 3) { LED15 = 1; }
    if (seq == 4) { LED16 = 1; }
  }
  if (die == 2) {
    if (seq == 1) { LED17 = 1; }
    if (seq == 2) { LED31 = 1; }
    if (seq == 3) { LED30 = 1; }
    if (seq == 4) { LED11 = 1; }
  }
  if (die == 3) {
    if (seq == 1) { LED33 = 1; }
    if (seq == 2) { LED34 = 1; }
    if (seq == 3) { LED36 = 1; }
    if (seq == 4) { LED37 = 1; }
  }
}

void showresult(UINT8 die, UINT8 dval) {
  if (die == 1) {
    // Die 1 LED values
    // 1 = LED16
    // 2 = LED15
    // 3 = LED16 & LED32
    // 4 = LED15 & LED32
    // 5 = LED15 & LED16 & LED32
    // 6 = LED14 & LED15 & LED32
    if (dval == 1) { LED16 = 1; }
    if (dval == 2) { LED15 = 1; }
    if (dval == 3) { LED16 = 1, LED32 = 1; }
    if (dval == 4) { LED15 = 1, LED32 = 1; }
    if (dval == 5) { LED15 = 1, LED16 = 1, LED32 = 1; }
    if (dval == 6) { LED14 = 1, LED15 = 1, LED32 = 1; }
  }
  if (die == 2) {
    // Die 2 LED values
    // 1 = LED11
    // 2 = LED30
    // 3 = LED11 & LED17
    // 4 = LED30 & LED17
    // 5 = LED30 & LED11 & LED17
    // 6 = LED31 & LED30 & LED17
    if (dval == 1) { LED11 = 1; }
    if (dval == 2) { LED30 = 1; }
    if (dval == 3) { LED11 = 1, LED17 = 1; }
    if (dval == 4) { LED30 = 1, LED17 = 1; }
    if (dval == 5) { LED30 = 1, LED11 = 1, LED17 = 1; }
    if (dval == 6) { LED31 = 1, LED30 = 1, LED17 = 1; }
  }
  if (die == 3) {
    // Die 3 LED values
    // 1 = LED37
    // 2 = LED36
    // 3 = LED37 & LED33
    // 4 = LED36 & LED33
    // 5 = LED36 & LED37 & LED33
    // 6 = LED34 & LED36 & LED33
    if (dval == 1) { LED37 = 1; }
    if (dval == 2) { LED36 = 1; }
    if (dval == 3) { LED37 = 1, LED33 = 1; }
    if (dval == 4) { LED36 = 1, LED33 = 1; }
    if (dval == 5) { LED36 = 1, LED37 = 1, LED33 = 1; }
    if (dval == 6) { LED34 = 1, LED36 = 1, LED33 = 1; }
  }
}

void main() {
    CfgFsys();

    // Read seed from data flash
    addrn = 1, lenn = 2, seed = 0;  // Note: seed is UINT16 but flash buff works with UINT8
    for( i=0; i < lenn; i++ ) {
      ReadDataFlash(addrn+i,1,&buffn[i]);
    }
    // create the seed number from the flash data
    seed = *(UINT16*)&buffn;        // Reads the 2 bytes of buffn array into seed

    // Get some random numbers for die results
    // srand seeds the random
    srand(seed);

    // rand() % 6 = 0-5, add 1 to make it 1-6
    d6value[0] = (rand() % 6) + 1;
    d6value[1] = (rand() % 6) + 1;
    d6value[2] = (rand() % 6) + 1;

    // generate a new random seed
    seed = rand();
    *(UINT16*)&buffn = seed;        // Writes the 2 bytes of seed into buffn array
    // Write seed to data flash
    for( i=0; i < lenn; i++ ) {
      WriteDataFlash(addrn+i,&buffn[i],1);
    }

    // USB UDP/UDM I/O pin enable: 0=P3.6/P3.7 as GPIO, 1=P3.6/P3.7 as USB
    // Clear this bit to use D+/D- as GPIO 3.6/3.7
    PIN_FUNC &= ~bUSB_IO_EN;

    /* *************************************************************************
    * Set mode for GPIO Pins 1.[0-7] and 3.[0-7]
    * *******************************************
    * Port1Cfg(mode,pin); / Port3Cfg(mode,pin);
    * Mode 0 = Floating input, no pull-up
    * Mode 1 = Push-pull input and output
    * Mode 2 = Open drain input and output, no pull-up
    * Mode 3 = quasi-bidirectional (standard 8051 mode),
    *          open-drain input and output, pull-up,
    *          internal circuit can accelerate level climb from low to high
    ************************************************************************* */
    Port1Cfg(1,1);      // Set mode 1 on Pin 1.1
    Port1Cfg(1,4);      // Set mode 1 on Pin 1.4
    Port1Cfg(1,5);      // Set mode 1 on Pin 1.5
    Port1Cfg(1,6);      // Set mode 1 on Pin 1.6
    Port1Cfg(1,7);      // Set mode 1 on Pin 1.7
    Port3Cfg(1,0);      // Set mode 1 on Pin 3.0
    Port3Cfg(1,1);      // Set mode 1 on Pin 3.1
    Port3Cfg(1,2);      // Set mode 1 on Pin 3.2
    Port3Cfg(1,3);      // Set mode 1 on Pin 3.3
    Port3Cfg(1,4);      // Set mode 1 on Pin 3.4
    Port3Cfg(1,6);      // Set mode 1 on Pin 3.6
    Port3Cfg(1,7);      // Set mode 1 on Pin 3.7

    // Make sure all LEDs are set to OFF before entering loop
    alloff();

    while (TRUE) {
      // *************
      // * MAIN LOOP *
      // *************

      // Animate die roll then display results one die at a time
      for ( i=0; i < 13; i++ ) {
        if ( i < 4 ) {                              // i = 0, 1, 2, 3
          // Initial roll - all dice at same speed
          rollani(1,1), rollani(2,2), rollani(3,3), mDelaymS(60);
          alloff();
          rollani(1,2), rollani(2,3), rollani(3,1), mDelaymS(60);
          alloff();
          rollani(1,3), rollani(2,1), rollani(3,2), mDelaymS(60);
          alloff();
        }
        if ( ( i >= 4 ) && ( i < 8 ) ) {            // i = 4, 5, 6, 7
          // Start slowing down dice before display
          // 20*i = 80, 100, 120, 140
          rollani(1,1), rollani(2,2), rollani(3,3), mDelaymS( 20 * i );
          alloff();
          rollani(1,2), rollani(2,3), rollani(3,1), mDelaymS( 20 * i );
          alloff();
          rollani(1,3), rollani(2,1), rollani(3,2), mDelaymS( 20 * i );
          alloff();
        }
        // Display die 1
        if ( i == 8) { showresult(1, d6value[0]); }       // i = 8
        if ( ( i >= 8 ) && ( i < 10 ) ) {           // i = 8, 9
          // Keep rolling die 2 and die 3 until display
          rollani(2,2), rollani(3,3), mDelaymS(140);
          dieoff(2), dieoff(3);
          rollani(2,3), rollani(3,1), mDelaymS(140);
          dieoff(2), dieoff(3);
          rollani(2,1), rollani(3,2), mDelaymS(140);
          dieoff(2), dieoff(3);
        }
        // Display die 2
        if ( i == 10) { showresult(2, d6value[1]); }      // i = 10
        if ( ( i >= 10 ) && ( i < 12 ) ) {          // i = 10, 11
          // Keep rolling die 3 until display
          rollani(3,3), mDelaymS(140);
          dieoff(3);
          rollani(3,1), mDelaymS(140);
          dieoff(3);
          rollani(3,2), mDelaymS(140);
          dieoff(3);
        }
        // Display die 3
        if ( i == 12) {                             // i = 12
          showresult(3, d6value[2]), mDelaymS(140);
        }
      }

      // Set i to 0 and Hold results steady for three seconds
      i = 0, mDelaymS(3000);

      // Start showing rolling animation again displaying same die results
      // Must reset or power cycle to get new die results
      while (TRUE) {
        randomdie = (rand() % 3) + 1; // Choose a die to roll, (rand()%3)+1 = 1-3
        for ( i=0; i < 11; i++ ) {
          if ( ( i >= 0 ) && ( i < 4 ) ) {          // i = 0, 1, 2, 3
            rollani(randomdie,1), mDelaymS(60);
            dieoff(randomdie);
            rollani(randomdie,2), mDelaymS(60);
            dieoff(randomdie);
            rollani(randomdie,3), mDelaymS(60);
            dieoff(randomdie);
          }
          if ( ( i >= 4 ) && ( i < 8 ) ) {            // i = 4, 5, 6, 7
            rollani(randomdie,1), mDelaymS( 20 * i );
            dieoff(randomdie);
            rollani(randomdie,2), mDelaymS( 20 * i );
            dieoff(randomdie);
            rollani(randomdie,3), mDelaymS( 20 * i );
            dieoff(randomdie);
          }
          if ( ( i >= 8 ) && ( i < 10 ) ) {          // i = 8, 9
            rollani(randomdie,1), mDelaymS(140);
            dieoff(randomdie);
            rollani(randomdie,2), mDelaymS(140);
            dieoff(randomdie);
            rollani(randomdie,3), mDelaymS(140);
            dieoff(randomdie);
          }
          if ( i == 10) {                             // i = 10
            showresult(randomdie, d6value[(randomdie - 1)]), mDelaymS(140); // always display die 3 until fixed
          }
        }

        // Set i to 0 and Hold results steady for two seconds
        i=0, mDelaymS(2000);

      }

    }
}

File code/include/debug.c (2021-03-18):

/********************************** (C) COPYRIGHT *******************************
* File Name          : Debug.C
* Author             : WCH
* Version            : V1.0
* Date               : 2017/01/20
* Description        : CH554 DEBUG Interface
                     CH554主频修改、延时函数定义
                     串口0和串口1初始化
                     串口0和串口1的收发子函数
                     看门狗初始化
*******************************************************************************/

#include <stdint.h>

#include "ch552.h"
#include "debug.h"

/*******************************************************************************
* Function Name  : CfgFsys( )
* Description    : CH554时钟选择和配置函数,默认使用Fsys 6MHz，FREQ_SYS可以通过
                   CLOCK_CFG配置得到，公式如下：
                   Fsys = (Fosc * 4/(CLOCK_CFG & MASK_SYS_CK_SEL);具体时钟需要自己配置
* Input          : None
* Output         : None
* Return         : None
*******************************************************************************/
void	CfgFsys( )
{
// 		SAFE_MOD = 0x55;
// 		SAFE_MOD = 0xAA;
//     CLOCK_CFG |= bOSC_EN_XT;                          //使能外部晶振
//     CLOCK_CFG &= ~bOSC_EN_INT;                        //关闭内部晶振

	SAFE_MOD = 0x55;
	SAFE_MOD = 0xAA;

#if FREQ_SYS == 32000000
	CLOCK_CFG = CLOCK_CFG & ~ MASK_SYS_CK_SEL | 0x07;  // 32MHz
#elif FREQ_SYS == 24000000
	CLOCK_CFG = CLOCK_CFG & ~ MASK_SYS_CK_SEL | 0x06;  // 24MHz
#elif FREQ_SYS == 16000000
	CLOCK_CFG = CLOCK_CFG & ~ MASK_SYS_CK_SEL | 0x05;  // 16MHz
#elif FREQ_SYS == 12000000
	CLOCK_CFG = CLOCK_CFG & ~ MASK_SYS_CK_SEL | 0x04;  // 12MHz
#elif FREQ_SYS == 6000000
	CLOCK_CFG = CLOCK_CFG & ~ MASK_SYS_CK_SEL | 0x03;  // 6MHz
#elif FREQ_SYS == 3000000
	CLOCK_CFG = CLOCK_CFG & ~ MASK_SYS_CK_SEL | 0x02;  // 3MHz
#elif FREQ_SYS == 750000
	CLOCK_CFG = CLOCK_CFG & ~ MASK_SYS_CK_SEL | 0x01;  // 750KHz
#elif FREQ_SYS == 187500
	CLOCK_CFG = CLOCK_CFG & ~ MASK_SYS_CK_SEL | 0x00;  // 187.5MHz
#else
	#warning FREQ_SYS invalid or not set
#endif

	SAFE_MOD = 0x00;
}



/*******************************************************************************
* Function Name  : mDelayus(UNIT16 n)
* Description    : us延时函数
* Input          : UNIT16 n
* Output         : None
* Return         : None
*******************************************************************************/
void	mDelayuS( uint16_t n )  // 以uS为单位延时
{
#ifdef	FREQ_SYS
#if		FREQ_SYS <= 6000000
		n >>= 2;
#endif
#if		FREQ_SYS <= 3000000
		n >>= 2;
#endif
#if		FREQ_SYS <= 750000
		n >>= 4;
#endif
#endif
	while ( n ) {  // total = 12~13 Fsys cycles, 1uS @Fsys=12MHz
		++ SAFE_MOD;  // 2 Fsys cycles, for higher Fsys, add operation here
#ifdef	FREQ_SYS
#if		FREQ_SYS >= 14000000
		++ SAFE_MOD;
#endif
#if		FREQ_SYS >= 16000000
		++ SAFE_MOD;
#endif
#if		FREQ_SYS >= 18000000
		++ SAFE_MOD;
#endif
#if		FREQ_SYS >= 20000000
		++ SAFE_MOD;
#endif
#if		FREQ_SYS >= 22000000
		++ SAFE_MOD;
#endif
#if		FREQ_SYS >= 24000000
		++ SAFE_MOD;
#endif
#if		FREQ_SYS >= 26000000
		++ SAFE_MOD;
#endif
#if		FREQ_SYS >= 28000000
		++ SAFE_MOD;
#endif
#if		FREQ_SYS >= 30000000
		++ SAFE_MOD;
#endif
#if		FREQ_SYS >= 32000000
		++ SAFE_MOD;
#endif
#endif
		-- n;
	}
}

/*******************************************************************************
* Function Name  : mDelayms(UNIT16 n)
* Description    : ms延时函数
* Input          : UNIT16 n
* Output         : None
* Return         : None
*******************************************************************************/
void	mDelaymS( uint16_t n )                                                  // 以mS为单位延时
{
	while ( n ) {
#ifdef	DELAY_MS_HW
		while ( ( TKEY_CTRL & bTKC_IF ) == 0 );
		while ( TKEY_CTRL & bTKC_IF );
#else
		mDelayuS( 1000 );
#endif
		-- n;
	}
}

/*******************************************************************************
* Function Name  : CH554UART0Alter()
* Description    : CH554串口0引脚映射,串口映射到P0.2和P0.3
* Input          : None
* Output         : None
* Return         : None
*******************************************************************************/
void CH554UART0Alter()
{
    PIN_FUNC |= bUART0_PIN_X;                                                  //串口映射到P1.2和P1.3
}


/*******************************************************************************
* Function Name  : mInitSTDIO()
* Description    : CH554串口0初始化,默认使用T1作UART0的波特率发生器,也可以使用T2
                   作为波特率发生器
* Input          : None
* Output         : None
* Return         : None
*******************************************************************************/
void	mInitSTDIO( )
{
    volatile uint32_t x;
    volatile uint8_t x2;

    SM0 = 0;
    SM1 = 1;
    SM2 = 0;                                                                   //串口0使用模式1
                                                                               //使用Timer1作为波特率发生器
    RCLK = 0;                                                                  //UART0接收时钟
    TCLK = 0;                                                                  //UART0发送时钟
    PCON |= SMOD;
    x = 10 * FREQ_SYS / UART0_BAUD / 16;                                       //如果更改主频，注意x的值不要溢出
    x2 = x % 10;
    x /= 10;
    if ( x2 >= 5 ) x ++;                                                       //四舍五入

    TMOD = TMOD & ~ bT1_GATE & ~ bT1_CT & ~ MASK_T1_MOD | bT1_M1;              //0X20，Timer1作为8位自动重载定时器
    T2MOD = T2MOD | bTMR_CLK | bT1_CLK;                                        //Timer1时钟选择
    TH1 = 0-x;                                                                 //12MHz晶振,buad/12为实际需设置波特率
    TR1 = 1;                                                                   //启动定时器1
    TI = 1;
    REN = 1;                                                                   //串口0接收使能
}

/*******************************************************************************
* Function Name  : CH554UART0RcvByte()
* Description    : CH554UART0接收一个字节
* Input          : None
* Output         : None
* Return         : SBUF
*******************************************************************************/
uint8_t  CH554UART0RcvByte( )
{
    while(RI == 0);                                                            //查询接收，中断方式可不用
    RI = 0;
    return SBUF;
}

/*******************************************************************************
* Function Name  : CH554UART0SendByte(uint8_t SendDat)
* Description    : CH554UART0发送一个字节
* Input          : uint8_t SendDat；要发送的数据
* Output         : None
* Return         : None
*******************************************************************************/
void CH554UART0SendByte(uint8_t SendDat)
{
        SBUF = SendDat;                                                              //查询发送，中断方式可不用下面2条语句,但发送前需TI=0
        while(TI ==0);
        TI = 0;
}

#if SDCC < 370
void putchar(char c)
{
    while (!TI) /* assumes UART is initialized */
    ;
    TI = 0;
    SBUF = c;
}

char getchar() {
    while(!RI); /* assumes UART is initialized */
    RI = 0;
    return SBUF;
}
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

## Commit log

2021-02-14 Initial Template Load
    [Battery_Holder_3xAAA_Simple.step, CP_Radial_D6.3mm_P2.50mm.step, C_0603_1608Metric.step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]
2021-02-15 schematic work
    [altbier_pcb_3d6.sch]
2021-02-18 test die blink code
2021-02-18 expanded 3d6 test
    [altbier_pcb_3d6.sch]
2021-02-23 schematic rework with new button
    [TS3735PA_250GF.stp, altbier_pcb_3d6.kicad_pcb, altbier_pcb_3d6.sch]
2021-02-24 working count and roll die code and cleanup
2021-02-27 Principal artwork finished and added to PCB
2021-03-01 Artwork and PCB silkscreen updates
2021-03-01 final pcb updates and gerber plots for prototype run
    [altbier_pcb_3d6-B_Cu.gbl, altbier_pcb_3d6-B_Cu.gbr, altbier_pcb_3d6-B_Mask.gbr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]
2021-03-09 Updated design to allow for dual connect lanyard.
    [altbier_pcb_3d6-B_Cu.gbr, altbier_pcb_3d6-B_Mask.gbr, altbier_pcb_3d6-B_SilkS.gbr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]
2021-06-02 Documentation Updates
    [altbier_pcb_3d6-B_Cu.gbl, altbier_pcb_3d6-B_Mask.gbs, altbier_pcb_3d6-B_Paste.gbp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]

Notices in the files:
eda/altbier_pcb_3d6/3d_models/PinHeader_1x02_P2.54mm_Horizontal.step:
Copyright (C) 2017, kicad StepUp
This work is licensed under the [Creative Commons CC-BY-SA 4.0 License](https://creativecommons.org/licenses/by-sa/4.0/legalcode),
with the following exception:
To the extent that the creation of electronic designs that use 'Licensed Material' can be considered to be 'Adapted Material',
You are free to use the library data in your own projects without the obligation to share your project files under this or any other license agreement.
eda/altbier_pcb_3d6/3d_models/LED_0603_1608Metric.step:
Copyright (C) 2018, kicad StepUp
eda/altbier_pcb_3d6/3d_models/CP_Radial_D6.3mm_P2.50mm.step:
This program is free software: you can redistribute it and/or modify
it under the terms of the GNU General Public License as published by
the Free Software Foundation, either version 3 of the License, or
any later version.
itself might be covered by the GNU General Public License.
